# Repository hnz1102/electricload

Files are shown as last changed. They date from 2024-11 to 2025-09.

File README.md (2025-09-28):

<div align="center">
  <h1><code>Electric Load and Logger</code></h1>
  <p>
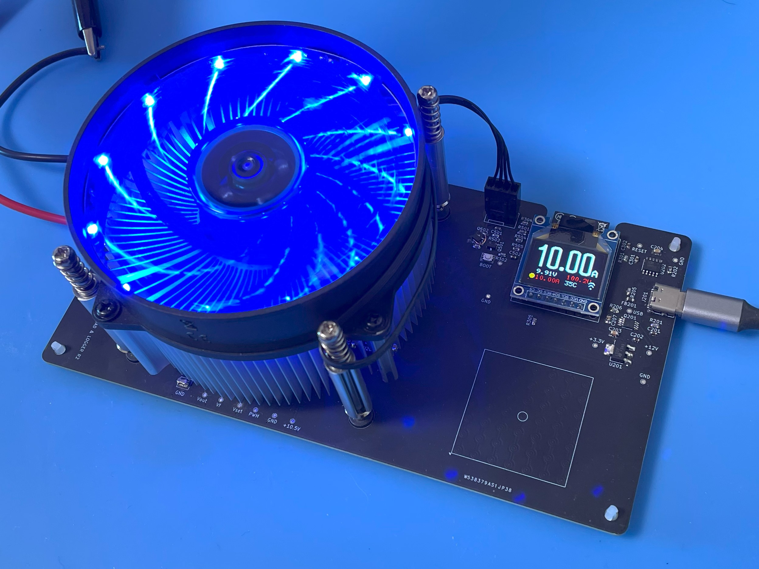
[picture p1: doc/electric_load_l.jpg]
    
  </p>
</div>

# Electric Load and Logger

This is an Electric Load and Logger. It can consume the power of the device and send the data to the server.
The maximum power is 100W, maximum voltage is 30V, and maximum current is 10A. But, it must be used under 100W.
And it can measure the voltage, current, and power consumption of the device and send the data to the InfluxDB server. You can see the data on the Dashboard.

# Feature

**High Power** - It can measure the power consumption of the device up to 100W.

**Controllable** - You can control the current consumption by the device. The current can be controlled every 10mA from 10mA to 10A.

**Auto Control** - The current consumption can be controlled automatically by the device using the PID controller.

**High-resolution** - By using Texas Instruments INA228 IC - 20-bit delta-sigma ADC, It can be got measurement data with 195.uV Bus voltage and 163.84mV Shunt voltage. 

**Microcontroller on board** - No need for a client PC when you are measuring. Directly send to the server. 

**Transfer measurement data via WiFi** - This Logger can transfer data to Linux PC via WiFi network and you can see the dashboard graph in influxDB.

**Internal Memory Buffer** - If the WiFi connection is not established, the data is stored in the internal memory buffer. When the WiFi connection is established, the data is sent to the server.

# How to use the Electric Load and Logger

At first, connect the power supply to this electric load as shown in the image below. The Plus line is connected to the 'Input +' terminal, and the GND line is connected to the 'Input -' terminal. And Input- is connected to the GND terminal, and Input+ is connected to the 'VBUS' terminal. This allows the device to measure the voltage.
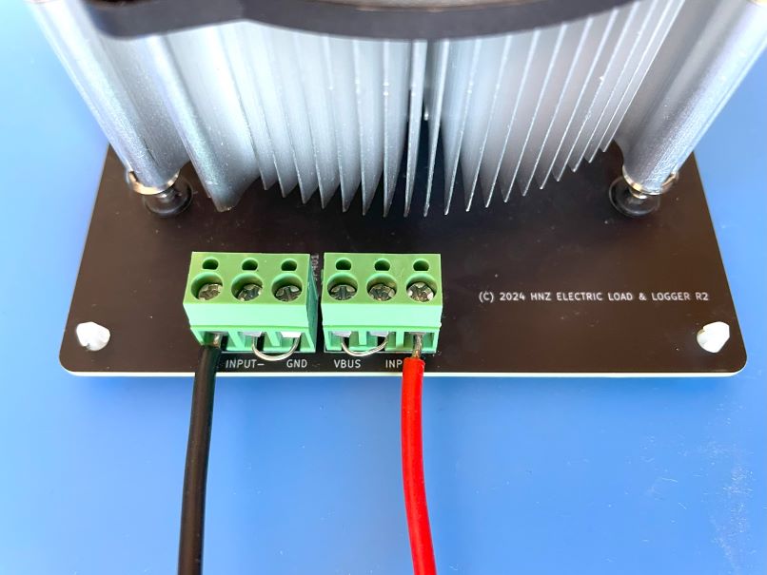
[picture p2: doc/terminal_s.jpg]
terminal


Then, connect the USB Power Delivery (PD) line to the USB-C port. The PD line must be connected to the USB PD Charger. This load gets power from the USB PD 12V.

After connecting the power supply, the display will show the current voltage, current, and power consumption. Then, you can set the current consumption by the device using the touch pad. Clockwise rotation increases the current, and counterclockwise rotation decreases the current. The current can be controlled every 10mA from 10mA to 10A. Fast rotation will increase or decrease the current quickly every 100mA. After setting the current, press the Center Position of the touch pad during over a second to start the load and measurement. The current consumption can be controlled automatically by the device using the PID controller.

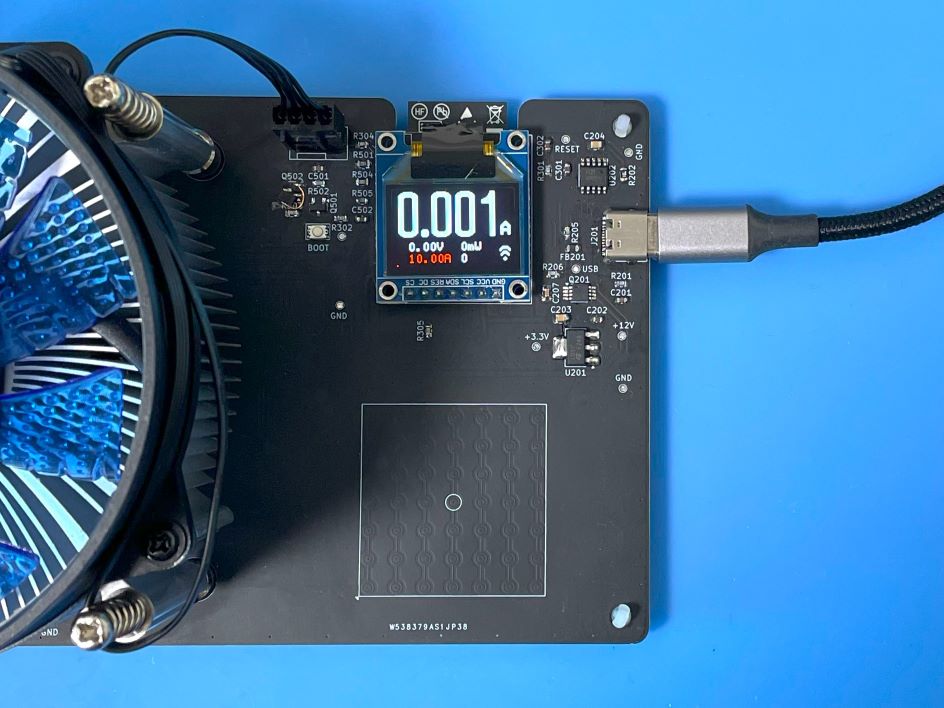
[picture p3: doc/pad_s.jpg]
pad


The display shows the current, voltage, power consumption, target current, temperature, PWM duty and status of the load. 
If you start the load, the display shows the yellow color circle in the left bottom corner and blinking. If the load is stopped, the circle disappears.
After the measure, the data is sent to the server. If the WiFi connection is not established, the data is stored in the internal memory buffer. When the WiFi connection is established, the data is sent to the server. However, the memory buffer is not stored more than 4096 samples. If the some data is stored in the memory buffer, the display shows the red bar in the bottom of the display. 

You can see the realtime data using Dashboard by [InfluxDB](https://www.influxdata.com/influxdb/).

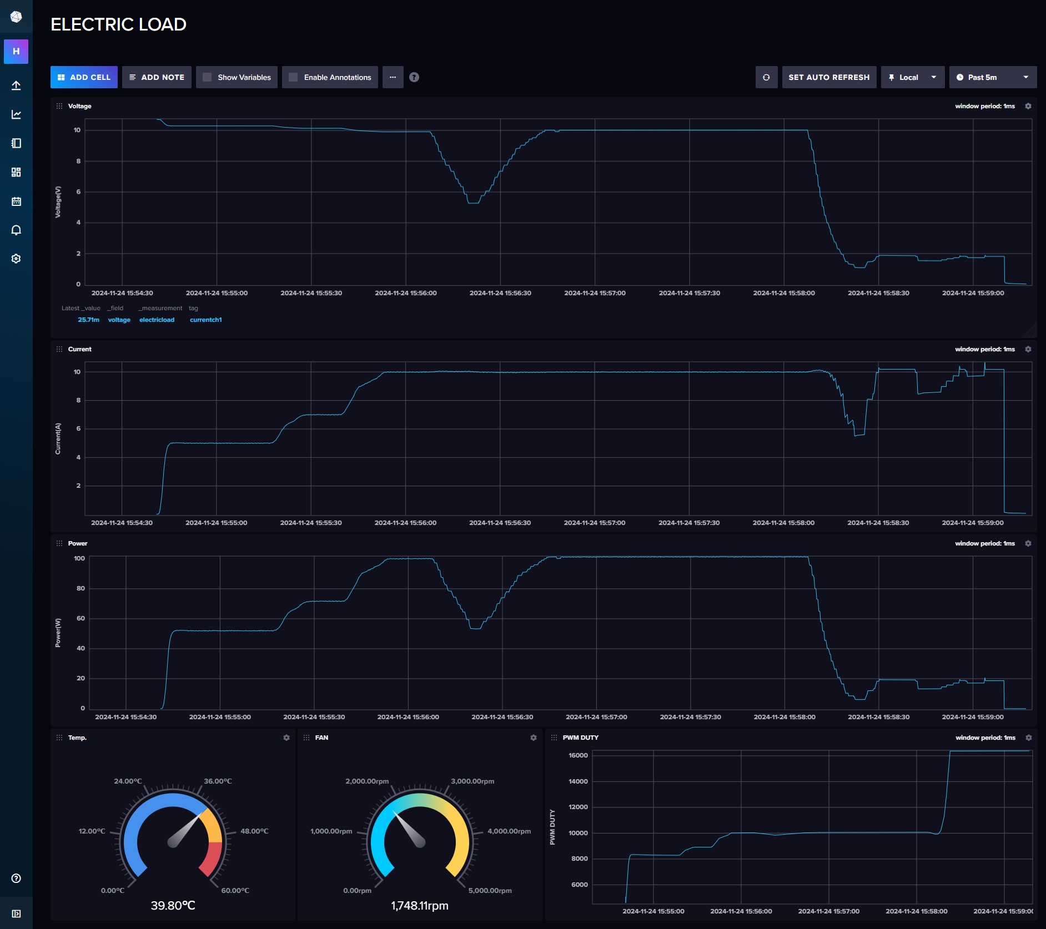
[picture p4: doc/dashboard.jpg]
dashboard


After the measure, to stop logging, press the Center Position of the touch pad during over a second. The load is stopped and the data is not sent to the server.

The dashboard shows the graphs of voltage, current, power consumption, and PWM duty. The temperature of the heat sink and FAN RPM also shown in the dashboard. 

# How to build from code and Install to the unit.

Using Ubuntu 22.04.3 LTS and ESP-IDF V5.2.1

## Prerequisites
Ensure that your system meets the following requirements before proceeding with the installation:
- Operating System: Linux-based distribution
- Required Packages: git, python3, python3-pip, gcc, build-essential, curl, pkg-config, libudev-dev, libtinfo5, clang, libclang-dev, llvm-dev, udev, libssl-dev, python3.10-venv

## Installation Steps

### 1. System Update and Package Installation
Update your system and install the necessary packages using:
```bash
sudo apt update && sudo apt -y install git python3 python3-pip gcc build-essential curl pkg-config libudev-dev libtinfo5 clang libclang-dev llvm-dev udev libssl-dev python3.10-venv
```

### 2. Rust Installation
Install Rust programming language and Cargo package manager:
```bash
curl --proto '=https' --tlsv1.2 -sSf https://sh.rustup.rs | sh
```
After installation, activate Rust by sourcing the environment:
```bash
. "$HOME/.cargo/env"
```

### 3. Additional Tools Installation
Install the following Rust tools:
- ldproxy
- espup
- cargo-espflash

Use the following commands:
```bash
cargo install ldproxy
cargo install espup
cargo install cargo-espflash
```
2024-08-12, cargo-espflash can not be compiled.
If you have an error, use the following command.
```bash
cargo install cargo-binstall
cargo binstall cargo-espflash 
```

### 4. ESP Environment Setup
Run the following command to install and update the Espressif Rust ecosystem:
```bash
espup install
espup update
```
Set up environment variables:
```bash
. ./export-esp.sh
```

### 5. Udev Rules Configuration
Configure udev rules for device permissions:
```bash
sudo sh -c 'echo "SUBSYSTEMS==\"usb\", ATTRS{idVendor}==\"303a\", ATTRS{idProduct}==\"1001\", MODE=\"0666\"" > /etc/udev/rules.d/99-esp32.rules'
sudo udevadm control --reload-rules
sudo udevadm trigger
```

### 6. Clone Repository
Clone the TimeLeapCam repository:
```bash
git clone https://github.com/hnz1102/electricload.git
cd electricload/code
```

### 7. Setting WiFi SSID, Password, etc.
Change the following configuration file: `cfg.toml`
You have to set the following parameters. WiFi SSID, Password, InfluxDB Server IP Address, InfluxDB API Key, and InfluxDB API with your ORG.
You can get the API Key from the InfluxDB Web Console. Please see the 'How to Install the influxDB and Configure the Dashboard' section No.3.

```bash
[electricload]
wifi_ssid = "<Your AP SSID>"  # Set your AP SSID
wifi_psk = "<Your AP Password>" # Set your AP Password
http_server = "<InfluxDB Server IP Address:Port>" # Set your InfluxDB Server IP Address and Port ex. 192.168.1.100:8086
pid_kp = "0.001"
pid_ki = "0.022"
pid_kd = "0.00001"
pwm_offset = "4500"
max_current_limit = "15.0"
max_power_limit = "105.0"
influxdb_api_key = "<InfluxDB API KEY>" # Set your InfluxDB API Key
influxdb_api = "/api/v2/write?org=<ORG>&bucket=LOGGER&precision=ns" # Set your InfluxDB API with your ORG and BUCKET ex. /api/v2/write?org=ORG&bucket=LOGGER&precision=ns
influxdb_tag = "currentch1"
influxdb_measurement = "electricload"
```

### 8. Build and Flash
Build the project.
```bash
cargo build --release
```

### 9. Flash the Firmware
Connect the Electric Load and Logger to your PC using a USB cable. Then, flash the firmware:
```bash
cargo espflash flash --release --monitor
```

If your device is not detected, power on the device and during the boot, press the `BOOT` button.
Then, run the flash command again.

### 10. Monitor the Output
After flashing the firmware, the console shows the booting messages.
```bash
[2024-11-24T08:43:44Z INFO ] 🚀 A new version of cargo-espflash is available: v3.2.0
[2024-11-24T08:43:44Z INFO ] Serial port: '/dev/ttyACM0'
[2024-11-24T08:43:44Z INFO ] Connecting...
[2024-11-24T08:43:44Z INFO ] Using flash stub
Finished `release` profile [optimized] target(s) in 0.19s
Chip type:         esp32s3 (revision v0.1)
Crystal frequency: 40 MHz
Flash size:        16MB
Features:          WiFi, BLE
MAC address:       xx:xx:xx:xx:xx:xx
Bootloader:        /esp32/electricload/code/target/xtensa-esp32s3-espidf/release/build/esp-idf-sys-37f4c3bc37bda4bb/out/build/bootloader/bootloader.bin
Partition table:   partitions.csv
App/part. size:    1,358,304/15,728,640 bytes, 8.64%
[2024-11-24T08:43:45Z INFO ] Segment at address '0x0' has not changed, skipping write
[2024-11-24T08:43:45Z INFO ] Segment at address '0x8000' has not changed, skipping write
[2024-11-24T08:43:46Z INFO ] Segment at address '0x10000' has not changed, skipping write
[2024-11-24T08:43:46Z INFO ] Flashing has completed!
Commands:
    CTRL+R    Reset chip
    CTRL+C    Exit

ESP-ROM:esp32s3-20210327
Build:Mar 27 2021
rst:0x15 (USB_UART_CHIP_RESET),boot:0x8 (SPI_FAST_FLASH_BOOT)
Saved PC:0x40378bb6
0x40378bb6 - rtc_isr
    at ??:??
SPIWP:0xee
mode:DIO, clock div:2
load:0x3fce3810,len:0x178c
load:0x403c9700,len:0x4
load:0x403c9704,len:0xcbc
load:0x403cc700,len:0x2d9c
entry 0x403c9914
I (27) boot: ESP-IDF v5.2.2 2nd stage bootloader
I (27) boot: compile time Nov 22 2024 19:30:56
I (27) boot: Multicore bootloader
I (30) boot: chip revision: v0.1
I (34) boot.esp32s3: Boot SPI Speed : 40MHz
I (39) boot.esp32s3: SPI Mode       : DIO
I (44) boot.esp32s3: SPI Flash Size : 16MB
I (49) boot: Enabling RNG early entropy source...
I (54) boot: Partition Table:
I (58) boot: ## Label            Usage          Type ST Offset   Length
I (65) boot:  0 nvs              WiFi data        01 02 00009000 00006000
I (72) boot:  1 phy_init         RF data          01 01 0000f000 00001000
I (80) boot:  2 factory          factory app      00 00 00010000 00f00000
I (87) boot: End of partition table
I (91) esp_image: segment 0: paddr=00010020 vaddr=3c0e0020 size=52034h (335924) map
I (183) esp_image: segment 1: paddr=0006205c vaddr=3fc9ae00 size=04ce8h ( 19688) load
I (189) esp_image: segment 2: paddr=00066d4c vaddr=40374000 size=092cch ( 37580) load
I (200) esp_image: segment 3: paddr=00070020 vaddr=42000020 size=ddea0h (908960) map
I (427) esp_image: segment 4: paddr=0014dec8 vaddr=4037d2cc size=0dae8h ( 56040) load
I (453) boot: Loaded app from partition at offset 0x10000
I (453) boot: Disabling RNG early entropy source...
I (464) cpu_start: Multicore app
I (465) octal_psram: vendor id    : 0x0d (AP)
I (465) octal_psram: dev id       : 0x02 (generation 3)
I (468) octal_psram: density      : 0x03 (64 Mbit)
I (473) octal_psram: good-die     : 0x01 (Pass)
I (478) octal_psram: Latency      : 0x01 (Fixed)
I (484) octal_psram: VCC          : 0x01 (3V)
I (489) octal_psram: SRF          : 0x01 (Fast Refresh)
I (495) octal_psram: BurstType    : 0x01 (Hybrid Wrap)
I (500) octal_psram: BurstLen     : 0x01 (32 Byte)
I (506) octal_psram: Readlatency  : 0x02 (10 cycles@Fixed)
I (512) octal_psram: DriveStrength: 0x00 (1/1)
I (518) MSPI Timing: PSRAM timing tuning index: 4
I (523) esp_psram: Found 8MB PSRAM device
I (527) esp_psram: Speed: 80MHz
I (543) cpu_start: Pro cpu start user code
I (543) cpu_start: cpu freq: 160000000 Hz
I (543) cpu_start: Application information:
I (546) cpu_start: Project name:     libespidf
I (551) cpu_start: App version:      9e8d2c8-dirty
I (557) cpu_start: Compile time:     Nov 22 2024 19:30:46
I (563) cpu_start: ELF file SHA256:  000000000...
I (568) cpu_start: ESP-IDF:          v5.2.2
I (573) cpu_start: Min chip rev:     v0.0
I (578) cpu_start: Max chip rev:     v0.99 
I (582) cpu_start: Chip rev:         v0.1
I (587) heap_init: Initializing. RAM available for dynamic allocation:
I (594) heap_init: At 3FCA4390 len 00045380 (276 KiB): RAM
I (600) heap_init: At 3FCE9710 len 00005724 (21 KiB): RAM
I (607) heap_init: At 3FCF0000 len 00008000 (32 KiB): DRAM
I (613) heap_init: At 600FE010 len 00001FD8 (7 KiB): RTCRAM
I (619) esp_psram: Adding pool of 8192K of PSRAM memory to heap allocator
I (627) spi_flash: detected chip: gd
I (631) spi_flash: flash io: dio
W (635) pcnt(legacy): legacy driver is deprecated, please migrate to `driver/pulse_cnt.h`
W (643) i2c: This driver is an old driver, please migrate your application code to adapt `driver/i2c_master.h`
W (654) timer_group: legacy driver is deprecated, please migrate to `driver/gptimer.h`
W (663) ADC: legacy driver is deprecated, please migrate to `esp_adc/adc_oneshot.h`
I (671) sleep: Configure to isolate all GPIO pins in sleep state
I (678) sleep: Enable automatic switching of GPIO sleep configuration
I (685) main_task: Started on CPU0
I (695) esp_psram: Reserving pool of 32K of internal memory for DMA/internal allocations
I (695) main_task: Calling app_main()
I (715) electricload: [Limit] Current: 15A  Power: 105W
I (715) gpio: GPIO[15]| InputEn: 0| OutputEn: 0| OpenDrain: 0| Pullup: 0| Pulldown: 0| Intr:0 
I (725) gpio: GPIO[16]| InputEn: 0| OutputEn: 0| OpenDrain: 0| Pullup: 0| Pulldown: 0| Intr:0 
I (735) electricload::displayctl: Start Display Thread.
I (735) electricload: INA228 Config: FB6A
I (735) electricload: current_lsb=3.125e-5 shunt_cal_val=2048.0 shunt_cal=2048
I (745) electricload: Max duty: 16383
I (755) electricload: Max duty: 255
I (755) gpio: GPIO[42]| InputEn: 0| OutputEn: 0| OpenDrain: 0| Pullup: 0| Pulldown: 0| Intr:0 
I (765) gpio: GPIO[41]| InputEn: 0| OutputEn: 0| OpenDrain: 0| Pullup: 0| Pulldown: 0| Intr:0 
I (775) electricload::pulscount: Start puls count thread.
I (785) pp: pp rom version: e7ae62f
I (785) net80211: net80211 rom version: e7ae62f
I (805) wifi:wifi driver task: 3fcc2b98, prio:23, stack:6656, core=0
I (805) wifi:wifi firmware version: 3e0076f
I (805) wifi:wifi certification version: v7.0
I (805) wifi:config NVS flash: disabled
I (805) wifi:config nano formating: disabled
I (815) wifi:Init data frame dynamic rx buffer num: 32
I (815) wifi:Init static rx mgmt buffer num: 10
I (825) wifi:Init management short buffer num: 32
I (825) wifi:Init static tx buffer num: 16
I (825) wifi:Init tx cache buffer num: 32
I (835) wifi:Init static tx FG buffer num: 2
I (835) wifi:Init static rx buffer size: 1600
I (845) wifi:Init static rx buffer num: 10
I (845) wifi:Init dynamic rx buffer num: 32
I (845) wifi_init: rx ba win: 6
I (965) wifi_init: tcpip mbox: 32
I (965) wifi_init: udp mbox: 6
I (965) wifi_init: tcp mbox: 6
I (965) wifi_init: tcp tx win: 5760
I (975) wifi_init: tcp rx win: 5760
I (975) wifi_init: tcp mss: 1440
I (985) wifi_init: WiFi IRAM OP enabled
I (985) wifi_init: WiFi RX IRAM OP enabled
I (995) phy_init: phy_version 670,b7bc9b9,Apr 30 2024,10:54:13
I (1035) wifi:mode : sta ()
I (1035) wifi:enable tsf
I (3985) wifi:new:<4,0>, old:<1,0>, ap:<255,255>, sta:<4,0>, prof:1
I (3985) wifi:state: init -> auth (b0)
I (3985) wifi:state: auth -> assoc (0)
I (3995) wifi:state: assoc -> run (10)
I (4005) wifi:connected with xxxxxxxx, aid = 7, channel 4, BW20, bssid = xx:xx:xx:xx:xx:xx
I (4005) wifi:security: WPA2-PSK, phy: bgn, rssi: -36
I (4005) wifi:pm start, type: 1
I (4005) wifi:dp: 1, bi: 102400, li: 3, scale listen interval from 307200 us to 307200 us
I (4015) wifi:set rx beacon pti, rx_bcn_pti: 0, bcn_timeout: 25000, mt_pti: 0, mt_time: 10000
I (4025) wifi:AP's beacon interval = 102400 us, DTIM period = 1
I (4065) electricload::wifi: Wifi connected
I (4065) esp_idf_svc::sntp: Initializing
I (4065) esp_idf_svc::sntp: Initialization complete
I (4065) electricload: NTP Sync Start..
I (7475) electricload: NTP Sync Completed: 2024-11-24 08:43:53
I (7475) electricload::transfer: Start transfer thread.
I (7475) electricload::touchpad: Start TouchPad Read Thread.
I (7485) gpio: GPIO[18]| InputEn: 0| OutputEn: 0| OpenDrain: 0| Pullup: 0| Pulldown: 0| Intr:0 
I (7495) electricload: PID Controller: KP=0.001 KI=0.022 KD=0.00001
I (7585) electricload::touchpad: TouchPad4 threshold: 1529
I (7585) electricload::touchpad: TouchPad5 threshold: 1519
I (7585) electricload::touchpad: TouchPad6 threshold: 1433
I (7585) electricload::touchpad: TouchPad7 threshold: 1523
I (7595) electricload::touchpad: TouchPad8 threshold: 297
I (7605) electricload::touchpad: TouchPad3 threshold: 1436
I (7605) electricload::touchpad: TouchPad9 threshold: 291
I (7625) electricload::touchpad: TouchPad1 threshold: 325
I (7625) electricload::touchpad: TouchPad2 threshold: 1619
I (7625) electricload::touchpad: TouchPad14 threshold: 313
I (7645) electricload::touchpad: TouchPad13 threshold: 307
I (7645) electricload::touchpad: TouchPad12 threshold: 302
I (7645) electricload::touchpad: TouchPad11 threshold: 287
I (7645) electricload::touchpad: TouchPad10 threshold: 281
I (7665) electricload::touchpad: TouchPad charge discharge times: 500 -> 1000
```

## How to Install the influxDB and Configure the Dashboard

### 1. Download [influxDB](https://docs.influxdata.com/influxdb/v2.7/install/?t=Linux) and Install.
```bash
$ wget https://dl.influxdata.com/influxdb/releases/influxdb2-2.7.0-amd64.deb
$ sudo dpkg -i influxdb2-2.7.0-amd64.deb
$ sudo service influxdb start
```

### 2. Configure the influxDB

```
Connect to the 'http://<influxDB installed PC Address>:8086'
```
Click `GET STARTED` and set `Username`, `Password`, `Initial Organization Name`, and `Initial Bucket Name`
|Term|Value|
|---|---|
|Username|Set login username as influxDB administrator web console|
|Password|Set login password as influxDB administrator web console|
|Initial Organization Name| Organization Name ex. ORG|
|Initial Bucket Name| LOGGER |

After set them, click `CONTINUE`.

### 3. Copy the operator API token.

You can see the operator API token on the browser. YOU WON'T BE ABLE TO SEE IT AGAIN!
If you want to get new API token, click `API Tokens` menu form `Sources` Icon, then click `GENERATE API TOKEN` and select `All access token`, click `Save`.
You can see a new API token and get it.
After copy the token, click `CONFIGURE LATER`.

### 4. Import the Dashboard Template.

Click the `Dashboard` icon, and select `Import Dashboard` from the `CREATE DASHBOARD` menu.

Drop the `influxdb/electric_load.json` file to `Drop a file here`, then click `IMPORT JSON AS DASHBOARD`.

You can see the `ELECTRIC LOAD` pannel on the Dashboards page.

Click this panel, and You can see the dashboard.

If you want to customize the dashboard design, click configure mark. You can change the graph design.

## Schematic, PCB Gabar Data

There is a Schematic data in hardware directory. 
If you want to make the PCB, you can order the [PCBway](https://www.pcbway.com/project/shareproject/Digitally_Controlled_Electric_Load_504eb052.html) this link.
The heat sink is not included in the schematic data. You can use the heat sink with the fan for LGA115x CPU Cooler. 

I used this [heat sink](https://www.ainex.jp/products/cc-06b/)

I guess another [heat sink](https://www.tronwire.com/collections/tronwire-cpu-coolers/products/tw-10) is also good.

This PCB is designed by [Kicad](https://www.kicad.org/). This board image photo is shown the jumper wire. But, the PCB data is already fixed the error.

UPDATE 2024-12-29: I changed the OpAmp from TSB6111ILT to OPA187IDBVR. OPA187IDBVR is a low noise and low offset voltage OpAmp. It can be used for the high precision control.

# Changelog

## v0.1.2
- **PID Control Enhancement**: Improved PID controller performance for better current regulation and stability.
- **Under Voltage Protection**: Added `under_voltage_limit` configuration parameter. When the voltage drops below this threshold, the PID controller is reset to prevent inrush current during startup or low voltage conditions.
- **Overcurrent Protection**: Implemented overcurrent protection using `max_current_limit_ratio` parameter. When the actual current exceeds the set current multiplied by this ratio, the PID controller is reset and output is set to zero to protect against excessive current flow.
- **Inrush Current Suppression**: These protection mechanisms work together to suppress inrush current during startup and abnormal conditions, ensuring safer operation.

**Note: After updating to v0.1.2, it is necessary to reconfigure the `cfg.toml` file to include the new parameters. Some PID parameters are changed, so please update them accordingly.**

## v0.1.1
- **NVS Configuration Persistence**: Added functionality to save the last load current setting to NVS (Non-Volatile Storage) and restore it on the next startup. This allows the device to remember the previous current setting even after power cycles or resets.
- **ESP-IDF Update**: Updated ESP-IDF from v5.2.1 to v5.4.2 for improved stability and latest features.
- **WiFi Reconnection Enhancement**: Added automatic WiFi reconnection functionality to maintain network connectivity during temporary disconnections.
- **Voltage Measurement Correction**: Fixed bus voltage resolution from 193.3125µV to 195.3125µV for more accurate voltage measurements.

## LICENSE
This source code is licensed under MIT. Other Hardware Schematic documents are licensed under CC-BY-SA V4.0.

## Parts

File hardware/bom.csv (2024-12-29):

Reference | Value | Footprint | Qty | digikey | distributor
C201,C202,C205,C301,C302,C404,C405,C408,C410,C501,C502 | 0.1uF | Capacitor_SMD:C_0603_1608Metric | 11 | 311-1343-1-ND | https://www.digikey.com/en/products/detail/yageo/CC0603ZRY5V9BB104/2103081
C203,C206,C208,C401,C403 | 10uF | Capacitor_SMD:C_0805_2012Metric | 5 | 311-3494-1-ND | https://www.digikey.com/en/products/detail/murata-electronics/GRM21BR61C106KE15K/2546903
C204,C402,C406 | 1uF | Capacitor_SMD:C_0805_2012Metric | 3 | 311-1365-1-ND | https://www.digikey.jp/en/products/detail/yageo/CC0805KKX7R7BB105/2103103
C207 | 2.2uF | Capacitor_SMD:C_0805_2012Metric | 1 | 311-1463-1-ND | https://www.digikey.jp/en/products/detail/yageo/CC0805ZRY5V7BB225/2833628
C407 | 4.7uF | Capacitor_SMD:C_0805_2012Metric | 1 | 311-1907-1-ND | https://www.digikey.jp/en/products/detail/yageo/CC0805ZKY5V7BB475/5195313
C409 | 1000pF | Capacitor_SMD:C_0603_1608Metric | 1 | 311-4063-1-ND | https://www.digikey.jp/en/products/detail/yageo/CC0603KRX7R7BB102/5883752
D401 | MBR3060FCT | Package_TO_SOT_THT:TO-220-3_Horizontal_TabUp | 1 | 3757-MBR3060FCT_T0_00001-ND | https://www.digikey.jp/en/products/detail/panjit-international-inc/MBR3060FCT-T0-00001/15800233
FB201 | MH2029-601Y | Inductor_SMD:L_0805_2012Metric | 1 | MH2029-601YCT-ND | https://www.digikey.com/en/products/detail/bourns-inc/MH2029-601Y/3741762
J201 | USB4105-GF-A | Library:USB_C_5077CR-16-SMC2-BK-TR | 1 | 2073-USB4105-GF-ACT-ND | https://www.digikey.com/en/products/detail/gct/USB4105-GF-A/11198441
J301 | FingerTouchPad | Library:FingerTouchPad_34x35mm | 1
J401,J402 | Screw_Terminal_3P | Library:TB112-2-2-3-E-1 Terminal Block | 2 |  | https://akizukidenshi.com/catalog/g/g101310/
J501 | 4PIN FANCTL | Connector:FanPinHeader_1x04_P2.54mm_Vertical | 1 | WM4330-ND | https://www.digikey.jp/en/products/detail/molex/0470531000/2421261
Q201 | IRF7606TRPBF | Package_SO:MSOP-8_3x3mm_P0.65mm | 1 | IRF7606TRPBFCT-ND | https://www.digikey.jp/en/products/detail/infineon-technologies/IRF7606TRPBF/856652
Q401 | IRF530PBF | Package_TO_SOT_THT:TO-220-3_Horizontal_TabUp | 1 | IRF530PBF-ND | https://www.digikey.jp/en/products/detail/vishay-siliconix/IRF530PBF/811781
Q501 | 2N7002K | Package_TO_SOT_SMD:SOT-23 | 1 | 2N7002KCT-ND | https://www.digikey.jp/en/products/detail/onsemi/2N7002K/2060348
Q502 | SSM3J332R | Package_TO_SOT_SMD:SOT-23 | 1 | 4518-SSM3J332RCT-ND | https://www.digikey.jp/en/products/detail/umw/SSM3J332R/24889390
R201,R205,R206,R301,R302,R305,R402,R403,R404,R502,R503,R505 | 10K | Resistor_SMD:R_0603_1608Metric | 12 | 13-RC0603JR-1010KLCT-ND | https://www.digikey.com/en/products/detail/yageo/RC0603JR-1010KL/13694233
R202,R405,R411,R412,R501 | 1K 1% | Resistor_SMD:R_0603_1608Metric | 5 | 311-1.00KHRCT-ND | https://www.digikey.jp/en/products/detail/yageo/RC0603FR-071KL/726843
R203 | 75K 1% | Resistor_SMD:R_0603_1608Metric | 1 | YAG3629CT-ND | https://www.digikey.jp/en/products/detail/yageo/AC0603FR-0775KL/5896284
R204,R401,R410 | 10K 1% | Resistor_SMD:R_0603_1608Metric | 3 | 311-10.0KHRCT-ND | https://www.digikey.jp/en/products/detail/yageo/RC0603FR-0710KL/726880
R303,R304 | 150R | Resistor_SMD:R_0603_1608Metric | 2 | 311-150GRCT-ND | https://www.digikey.jp/en/products/detail/yageo/RC0603JR-07150RL/726714
R406 | 2K 1% | Resistor_SMD:R_0603_1608Metric | 1 | 311-2.00KHRCT-ND | https://www.digikey.jp/en/products/detail/yageo/RC0603FR-072KL/727009
R407,R504 | 100 | Resistor_SMD:R_0603_1608Metric | 2 | 311-100GRCT-ND | https://www.digikey.jp/en/products/detail/yageo/RC0603JR-07100RL/726697
R408,R409 | 10m | Library:R_10mOHM | 2 |  | https://akizukidenshi.com/catalog/g/gP-01886/
SW301 | 3.5x2.6 Tact SW | Library:WS-TASV SMT Tact Switch | 1 | 732-435151014824CT-ND | https://www.digikey.com/en/products/detail/w%C3%BCrth-elektronik/435151014824/11627325
TP-PAD401 | TPGND | Library:TestPoint_Pad_3.2x1.6mm | 1 | 2019-RCWCTECT-ND | https://www.digikey.jp/en/products/detail/koa-speer-electronics-inc/RCWCTE/11476558
TP201 | +3.3V | TestPoint:TestPoint_Pad_D1.0mm | 1
TP202 | VBUS | TestPoint:TestPoint_Pad_D1.0mm | 1
TP203 | +12V | TestPoint:TestPoint_Pad_D1.0mm | 1
TP301 | RESET | TestPoint:TestPoint_Pad_D1.0mm | 1
TP302 | BOOT | TestPoint:TestPoint_Pad_D1.0mm | 1
TP401 | PWM | TestPoint:TestPoint_Pad_D1.0mm | 1
TP402 | SET-Vr | TestPoint:TestPoint_Pad_D1.0mm | 1
TP403 | Vfb | TestPoint:TestPoint_Pad_D1.0mm | 1
TP404 | OP-VCC | TestPoint:TestPoint_Pad_D1.0mm | 1
TP405,TP406,TP407,TP408,TP409 | GND | TestPoint:TestPoint_Pad_D1.0mm | 5
TP410 | Vgs | TestPoint:TestPoint_Pad_D1.0mm | 1
U201 | LD1117S33TR | Package_TO_SOT_SMD:SOT-223-3_TabPin2 | 1 | 497-1242-1-ND | https://www.digikey.com/en/products/detail/stmicroelectronics/LD1117S33TR/585766
U202 | CH224K | Library:ESSOP-10_3.9x4.9mm_P1.00mm | 1 |  | https://akizukidenshi.com/catalog/g/g118023/
U203 | SPX3819M5-L | Package_TO_SOT_SMD:SOT-23-5 | 1 | 1016-1871-1-ND | https://www.digikey.com/en/products/detail/maxlinear-inc/SPX3819M5-L-TR/2472388
U301 | ESP32-S3-WROOM-1-N16R8 | Library:ESP32-S3-WROOM-1_EXP | 1 | 1965-ESP32-S3-WROOM-1-N16R8CT-ND | https://www.digikey.com/en/products/detail/espressif-systems/ESP32-S3-WROOM-1-N16R8/16162642
U302 | SSD1331_DISPLAY | Library:OLED SSD1331 SPI DISPLAY | 1 |  | https://akizukidenshi.com/catalog/g/gP-14435/
U401 | OPA187IDBVR | Package_TO_SOT_SMD:SOT-23-5 | 1 | 296-53156-1-ND | https://www.digikey.com/en/products/detail/texas-instruments/OPA187IDBVR/9861469
U402 | INA228 | Package_SO:VSSOP-10_3x3mm_P0.5mm | 1 | 296-INA228AIDGSRCT-ND | https://www.digikey.com/en/products/detail/texas-instruments/INA228AIDGSR/13691042
U403 | LM35-NEB | Package_TO_SOT_THT:TO-220-3_Horizontal_TabDown | 1 | LM35DT/NOPB-ND | https://www.digikey.jp/en/products/detail/texas-instruments/LM35DT-NOPB/362706
U404 | TSB611ILT | Package_TO_SOT_SMD:SOT-23-5 | 1 | 497-16082-1-ND | https://www.digikey.jp/en/products/detail/stmicroelectronics/TSB611ILT/5639707

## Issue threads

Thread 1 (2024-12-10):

No issue at all, just congrats!

Karim-at-Powl, 2024-12-10:
That is such an elegant solution, ironically _exactly_ what I wanted to build!
You use INA228, you use ESP32-S3, you use Kicad.. heaven!
Found you through PCBway :)

I read something that might be interesting for you: Instead of using a single 14-bit PWM signal and LPF to control the FET-OPamp, you can instead have two or more PWM signals with different Filters wired in parallel. Imagine one main PWM with R = 1 kOhm and one auxiliary PWM with R = 10 kOhm. You can then use the auxPWM for fine tuning while maintaining high Frequency and good response time on the main PWM. Good luck!

hnz1102, 2024-12-11:
Thank you!

>  I read something that might be interesting for you: Instead of using a single 14-bit PWM signal and LPF to control the FET-OPamp, you can instead have two or more PWM signals with different Filters wired in parallel. Imagine one main PWM with R = 1 kOhm and one auxiliary PWM with R = 10 kOhm. You can then use the auxPWM for fine tuning while maintaining high Frequency and good response time on the main PWM.

That's good idea! I will try it with using unoccupied GPIO pin.

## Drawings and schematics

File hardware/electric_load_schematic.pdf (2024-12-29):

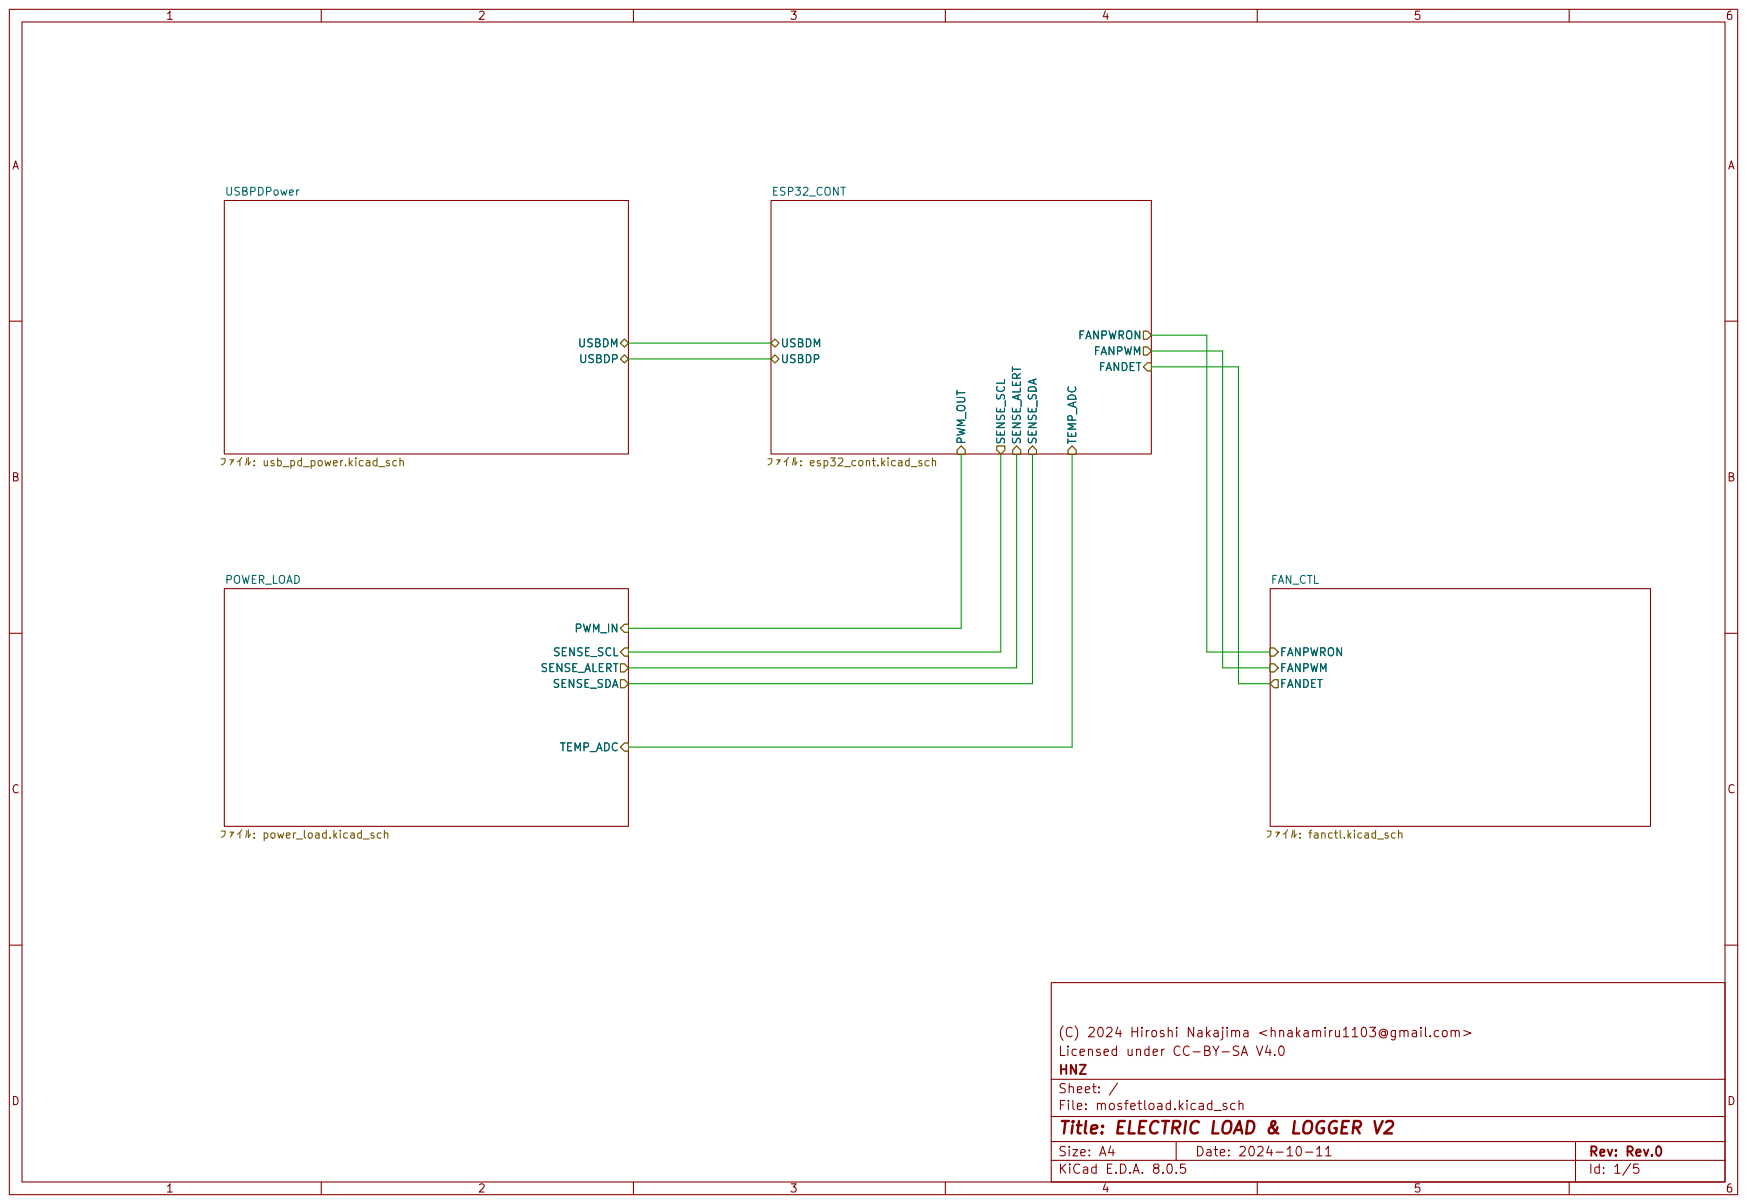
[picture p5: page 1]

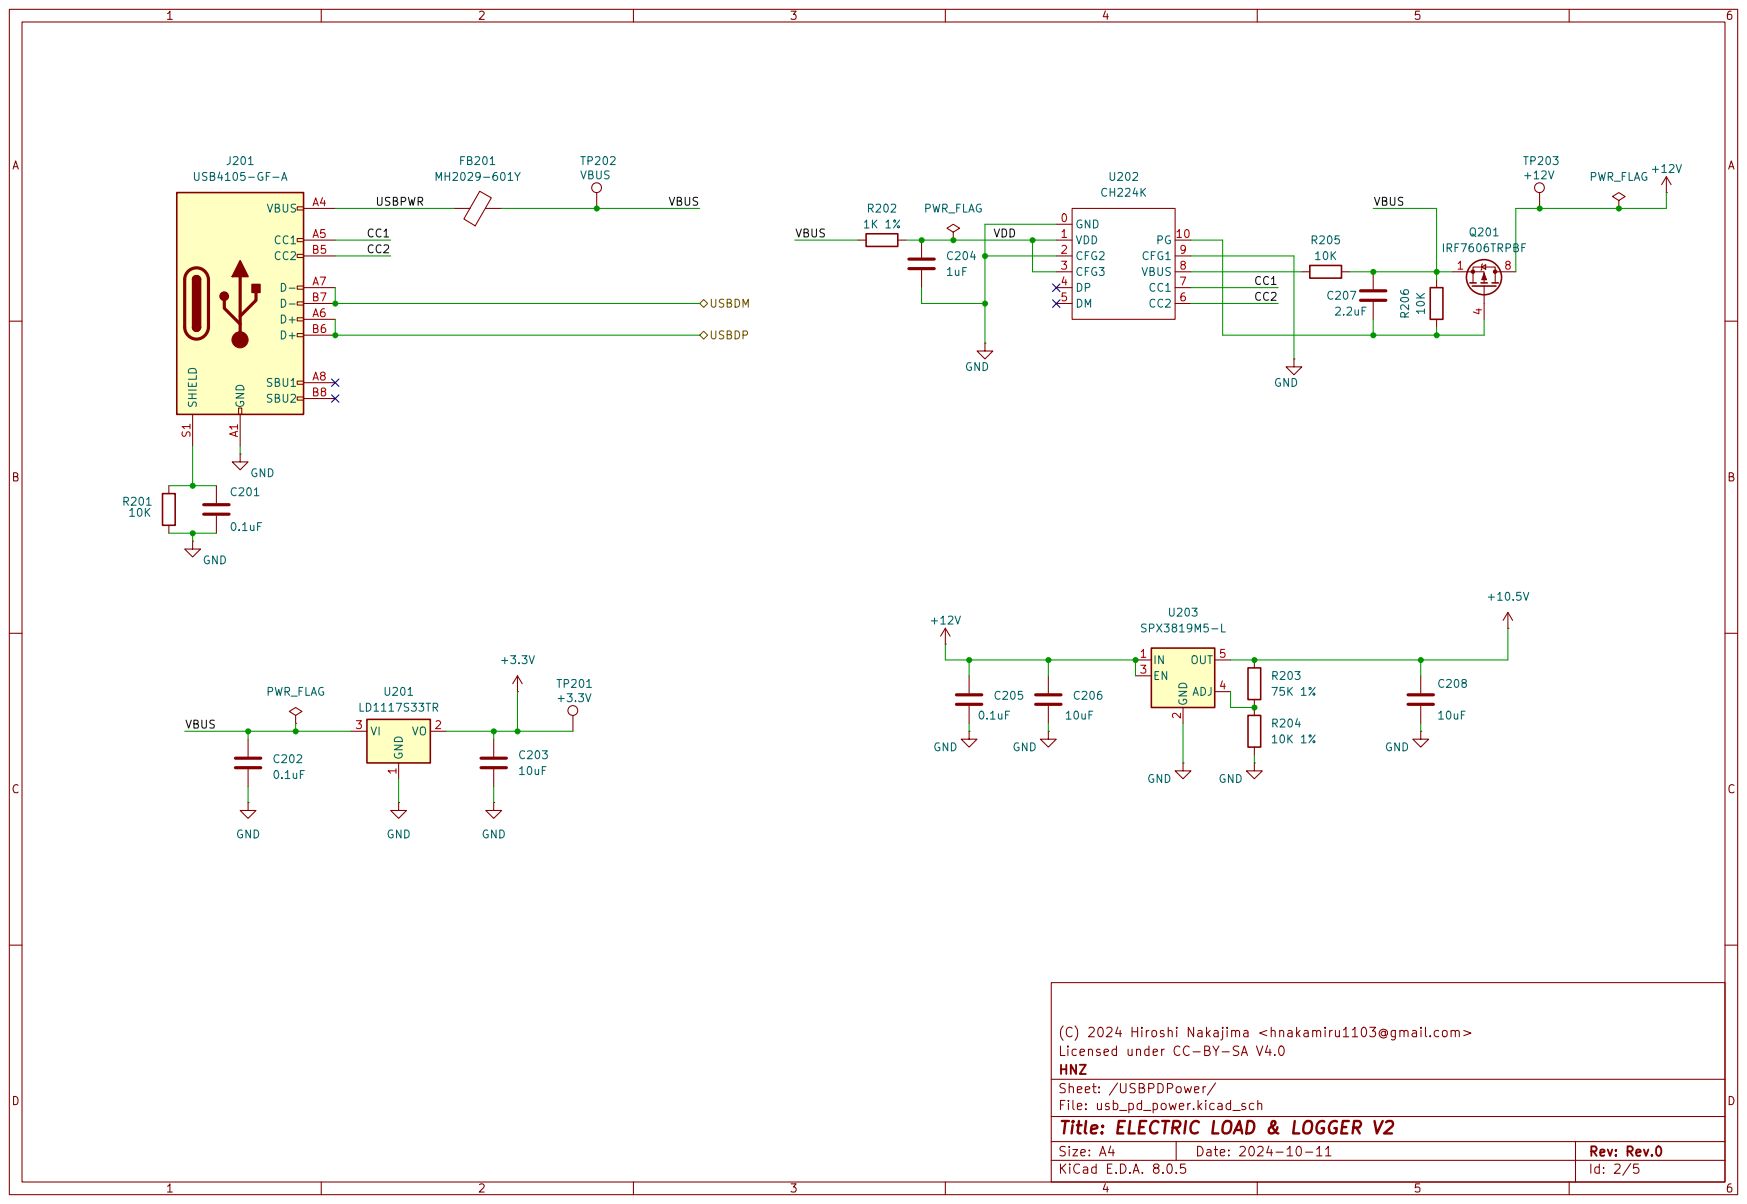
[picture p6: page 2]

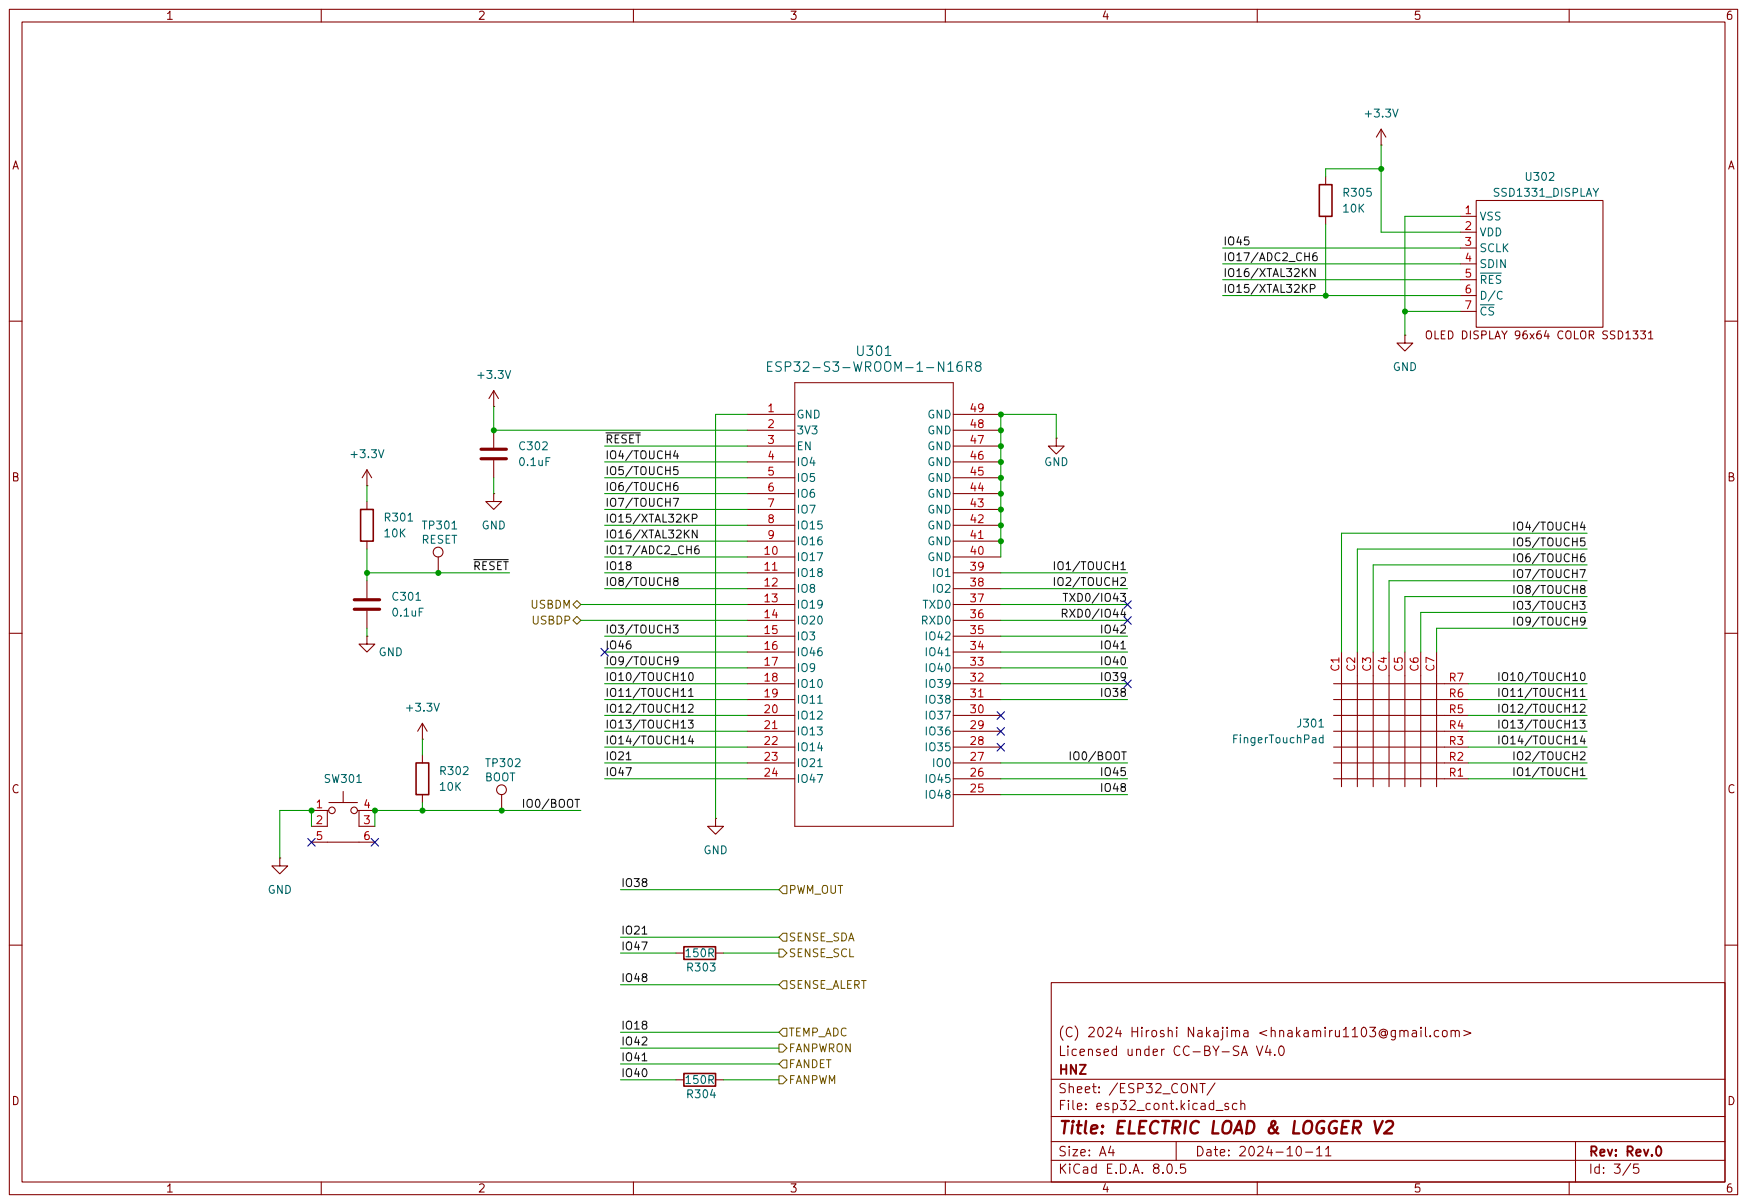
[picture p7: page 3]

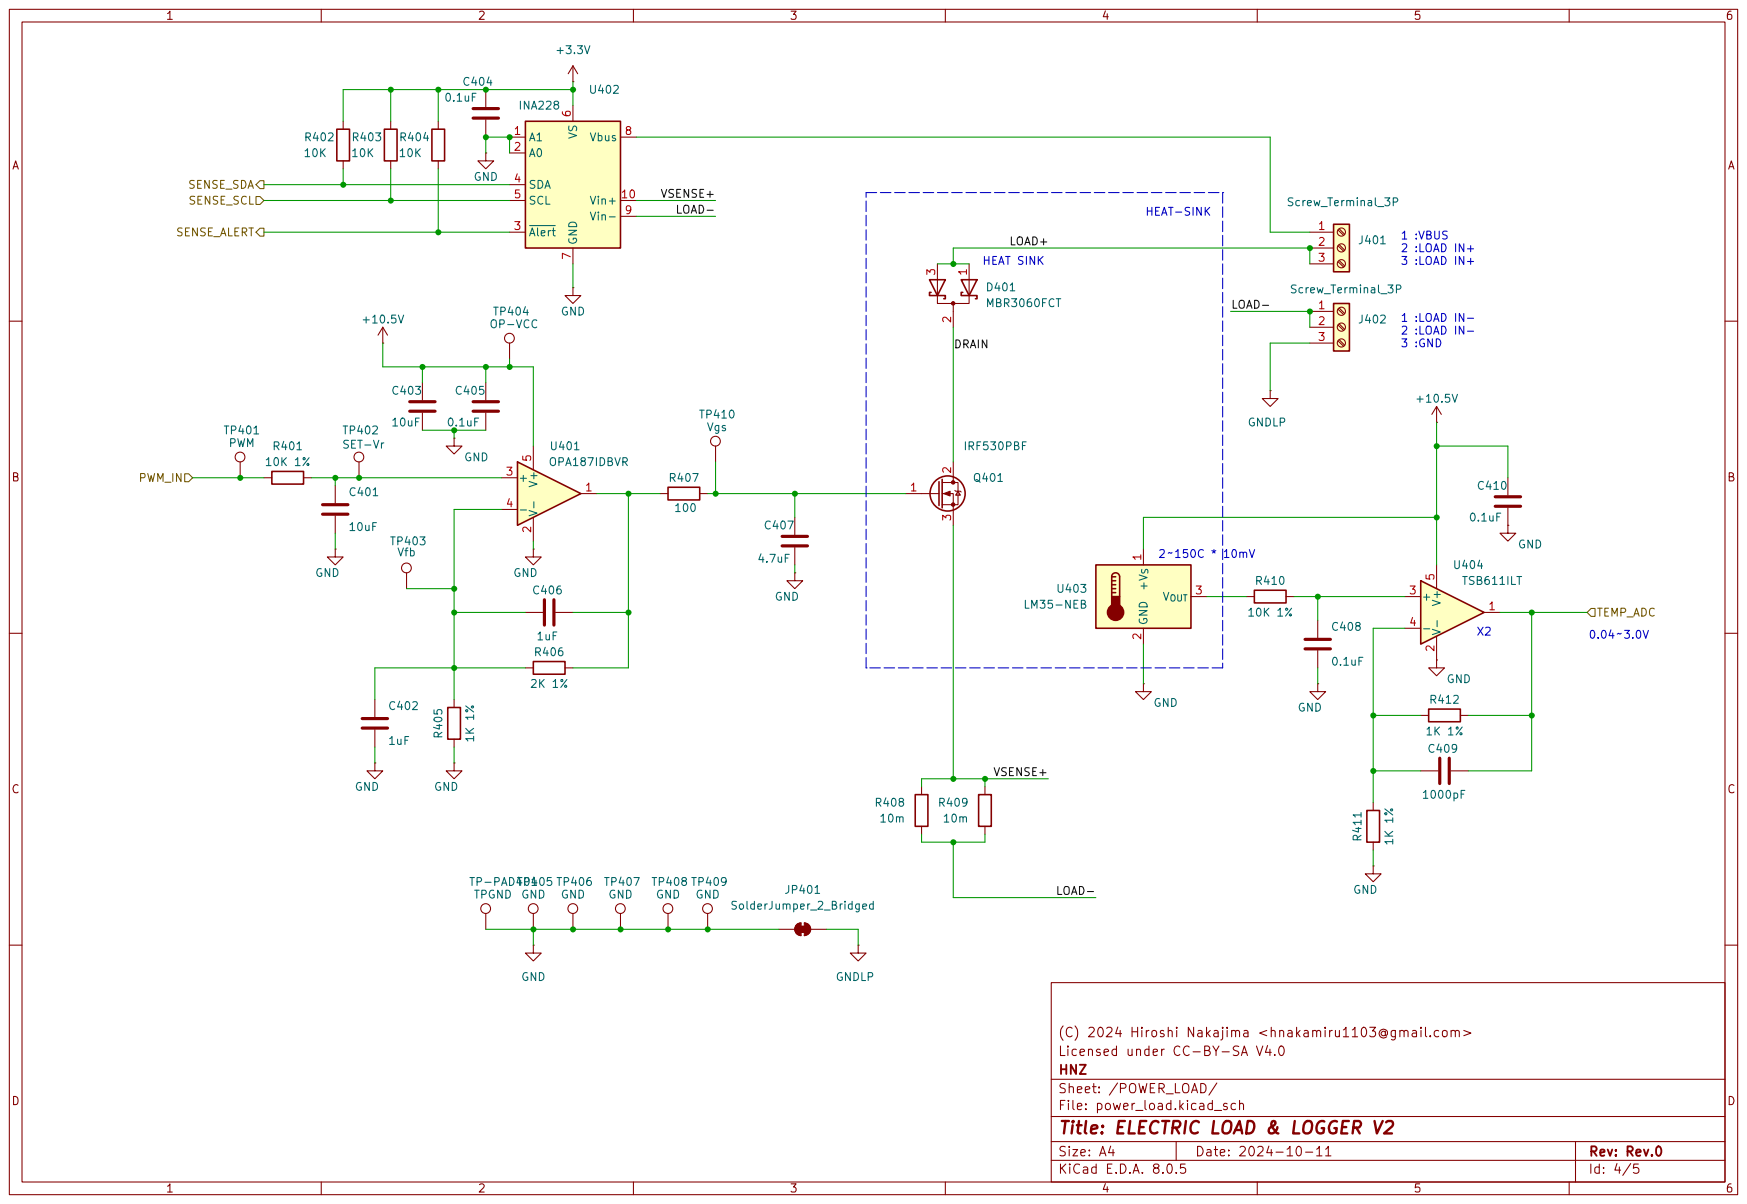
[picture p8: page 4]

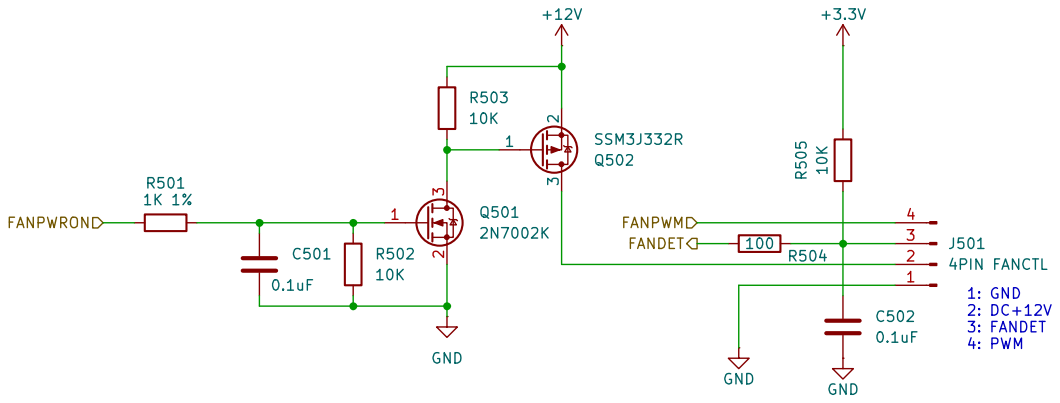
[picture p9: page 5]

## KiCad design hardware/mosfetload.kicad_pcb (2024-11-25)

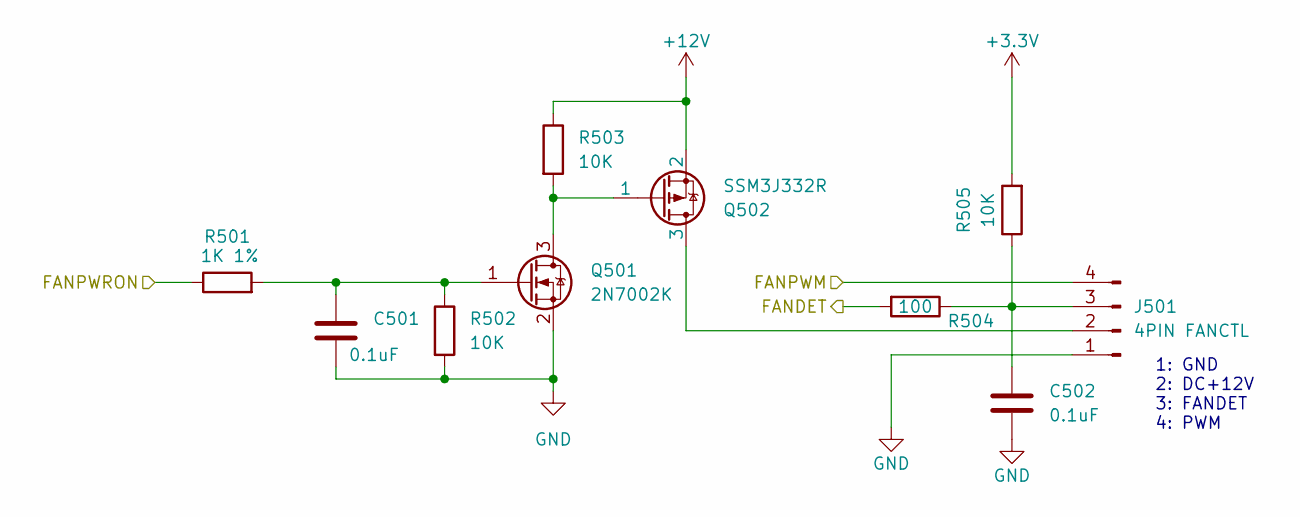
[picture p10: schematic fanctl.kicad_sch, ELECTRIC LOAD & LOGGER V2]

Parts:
C501, C502: 0.1uF; C_0603_1608Metric; digikey 311-1343-1-ND
J501: 4PIN FANCTL; FanPinHeader_1x04_P2.54mm_Vertical
Q501: 2N7002K; SOT-23; digikey 2N7002KCT-ND
Q502: SSM3J332R; SOT-23; digikey 4518-SSM3J332RCT-ND
R501: 1K 1%; R_0603_1608Metric; digikey 311-1.00KHRCT-ND
R502, R503, R505: 10K; R_0603_1608Metric; digikey 13-RC0603JR-1010KLCT-ND
R504: 100; R_0603_1608Metric; digikey 311-100GRCT-ND

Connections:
+3.3V: R505.2; also elsewhere on the board
+12V: Q502.2, R503.1; also elsewhere on the board
/ESP32_CONT/FANPWM: J501.4; also elsewhere on the board
/ESP32_CONT/IO41: R504.2; also elsewhere on the board
/ESP32_CONT/IO42: R501.1; also elsewhere on the board
GND: C501.2, C502.2, J501.1, Q501.2 (S), R502.2; also elsewhere on the board
unnamed: J501.2, Q502.3
unnamed: C502.1, J501.3, R504.1, R505.1
unnamed: Q501.3 (D), Q502.1, R503.2
unnamed: C501.1, Q501.1 (G), R501.2, R502.1

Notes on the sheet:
1: GND 2: DC+12V 3: FANDET 4: PWM

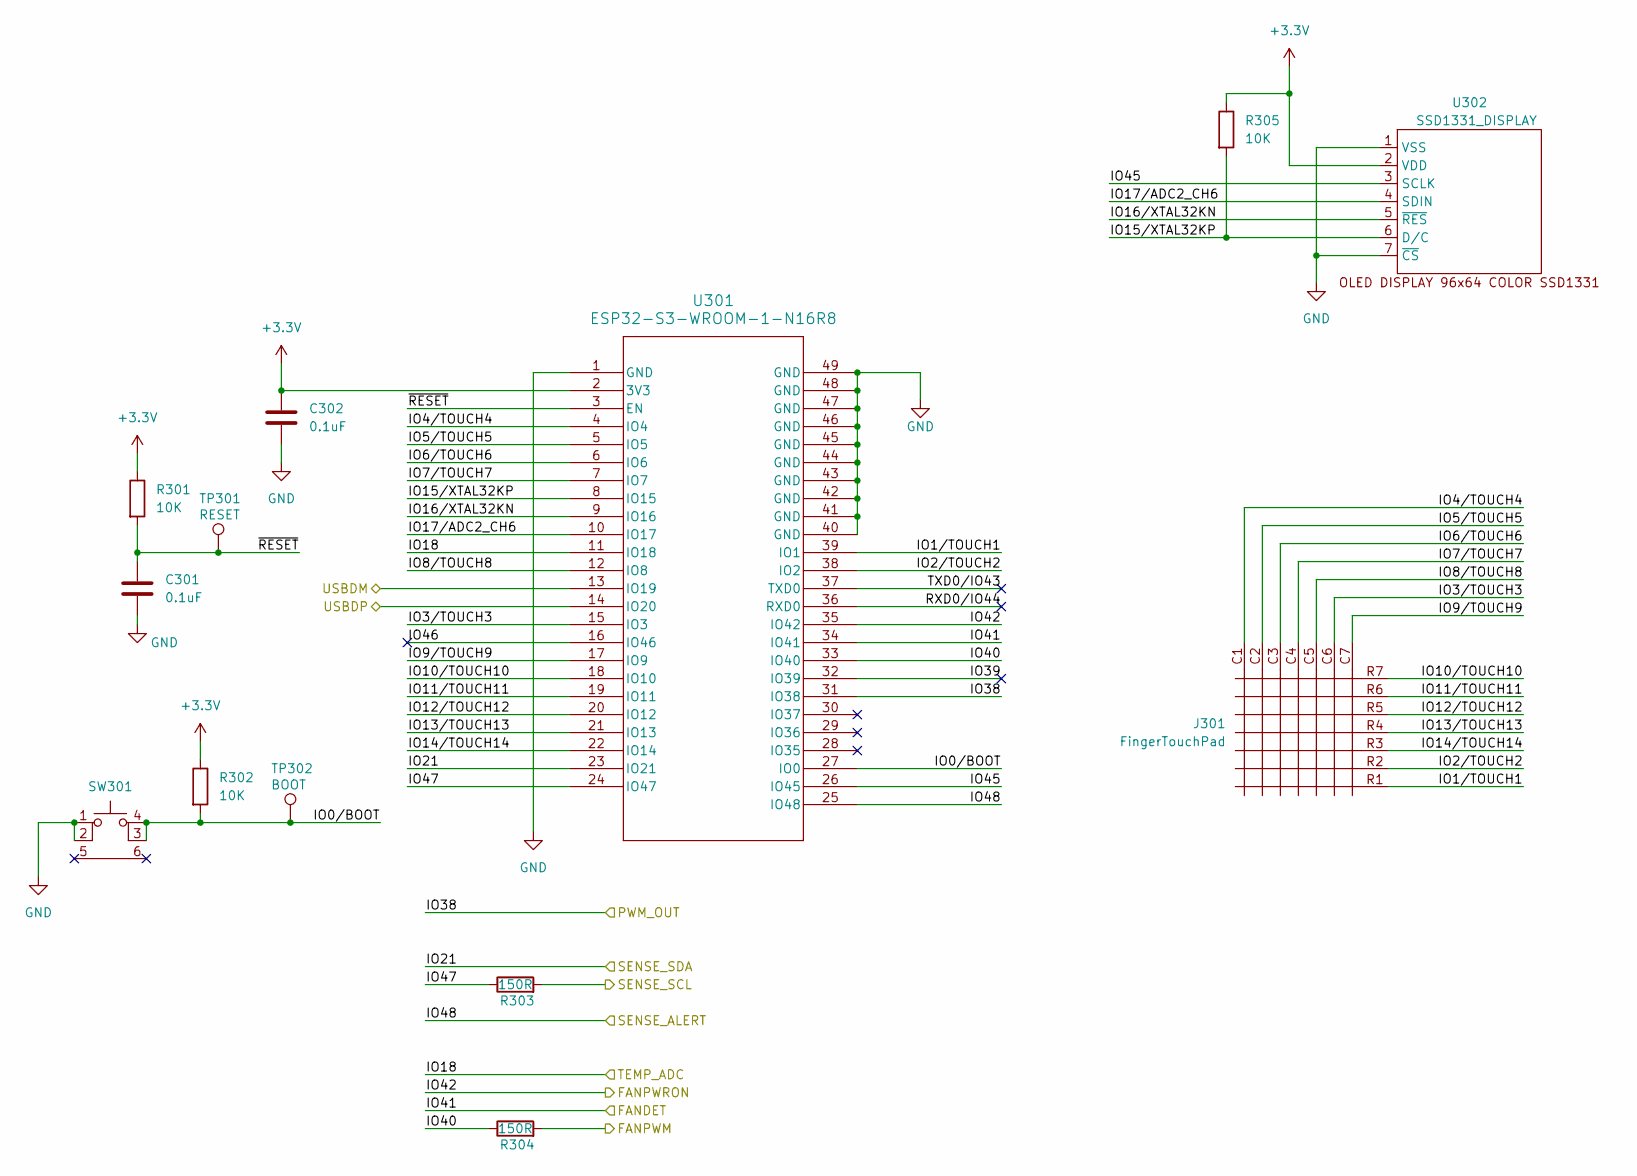
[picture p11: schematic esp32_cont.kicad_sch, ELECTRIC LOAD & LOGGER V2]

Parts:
C301, C302: 0.1uF; C_0603_1608Metric; digikey 311-1343-1-ND
J301: FingerTouchPad; FingerTouchPad_34x35mm
R301, R302, R305: 10K; R_0603_1608Metric; digikey 13-RC0603JR-1010KLCT-ND
R303, R304: 150R; R_0603_1608Metric; digikey 311-150GRCT-ND
SW301: 3.5x2.6 Tact SW; WS-TASV SMT Tact Switch; digikey 732-435151014824CT-ND
TP301: RESET; TestPoint_Pad_D1.0mm
TP302: BOOT; TestPoint_Pad_D1.0mm
U301: ESP32-S3-WROOM-1-N16R8; ESP32-S3-WROOM-1_EXP; digikey 1965-ESP32-S3-WROOM-1-N16R8CT-ND
U302: SSD1331_DISPLAY; OLED SSD1331 SPI DISPLAY

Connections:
+3.3V: C302.1, R301.1, R302.1, R305.1, U301.2 (3V3), U302.2 (VDD); also elsewhere on the board
/ESP32_CONT/FANPWM: R304.2; also elsewhere on the board
/ESP32_CONT/IO0/BOOT: R302.2, SW301.3 (K), SW301.4 (A), TP302.1, U301.27 (IO0)
/ESP32_CONT/IO1/TOUCH1: J301.R1, U301.39 (IO1)
/ESP32_CONT/IO2/TOUCH2: J301.R2, U301.38 (IO2)
/ESP32_CONT/IO3/TOUCH3: J301.C6, U301.15 (IO3)
/ESP32_CONT/IO4/TOUCH4: J301.C1, U301.4 (IO4)
/ESP32_CONT/IO5/TOUCH5: J301.C2, U301.5 (IO5)
/ESP32_CONT/IO6/TOUCH6: J301.C3, U301.6 (IO6)
/ESP32_CONT/IO7/TOUCH7: J301.C4, U301.7 (IO7)
/ESP32_CONT/IO8/TOUCH8: J301.C5, U301.12 (IO8)
/ESP32_CONT/IO9/TOUCH9: J301.C7, U301.17 (IO9)
/ESP32_CONT/IO10/TOUCH10: J301.R7, U301.18 (IO10)
/ESP32_CONT/IO11/TOUCH11: J301.R6, U301.19 (IO11)
/ESP32_CONT/IO12/TOUCH12: J301.R5, U301.20 (IO12)
/ESP32_CONT/IO13/TOUCH13: J301.R4, U301.21 (IO13)
/ESP32_CONT/IO14/TOUCH14: J301.R3, U301.22 (IO14)
/ESP32_CONT/IO15/XTAL32KP: R305.2, U301.8 (IO15), U302.6 (D/C)
/ESP32_CONT/IO16/XTAL32KN: U301.9 (IO16), U302.5 (~RES)
/ESP32_CONT/IO17/ADC2_CH6: U301.10 (IO17), U302.4 (SDIN)
/ESP32_CONT/IO18: U301.11 (IO18); also elsewhere on the board
/ESP32_CONT/IO21: U301.23 (IO21); also elsewhere on the board
/ESP32_CONT/IO38: U301.31 (IO38); also elsewhere on the board
/ESP32_CONT/IO39: U301.32 (IO39)
/ESP32_CONT/IO40: R304.1, U301.33 (IO40)
/ESP32_CONT/IO41: U301.34 (IO41); also elsewhere on the board
/ESP32_CONT/IO42: U301.35 (IO42); also elsewhere on the board
/ESP32_CONT/IO45: U301.26 (IO45), U302.3 (SCLK)
/ESP32_CONT/IO46: U301.16 (IO46)
/ESP32_CONT/IO47: R303.1, U301.24 (IO47)
/ESP32_CONT/IO48: U301.25 (IO48); also elsewhere on the board
/ESP32_CONT/RXD0/IO44: U301.36 (RXD0)
/ESP32_CONT/SENSE_SCL: R303.2; also elsewhere on the board
/ESP32_CONT/TXD0/IO43: U301.37 (TXD0)
/ESP32_CONT/USBDM: U301.13 (IO19); also elsewhere on the board
/ESP32_CONT/USBDP: U301.14 (IO20); also elsewhere on the board
/ESP32_CONT/~RESET: C301.1, R301.2, TP301.1, U301.3 (EN)
GND: C301.2, C302.2, SW301.1, SW301.2, U301.1 (GND), U301.40 (GND), U301.41 (GND), U301.42 (GND), U301.43 (GND), U301.44 (GND), U301.45 (GND), U301.46 (GND), U301.47 (GND), U301.48 (GND), U301.49 (GND), U302.1 (VSS), U302.7 (~CS); also elsewhere on the board

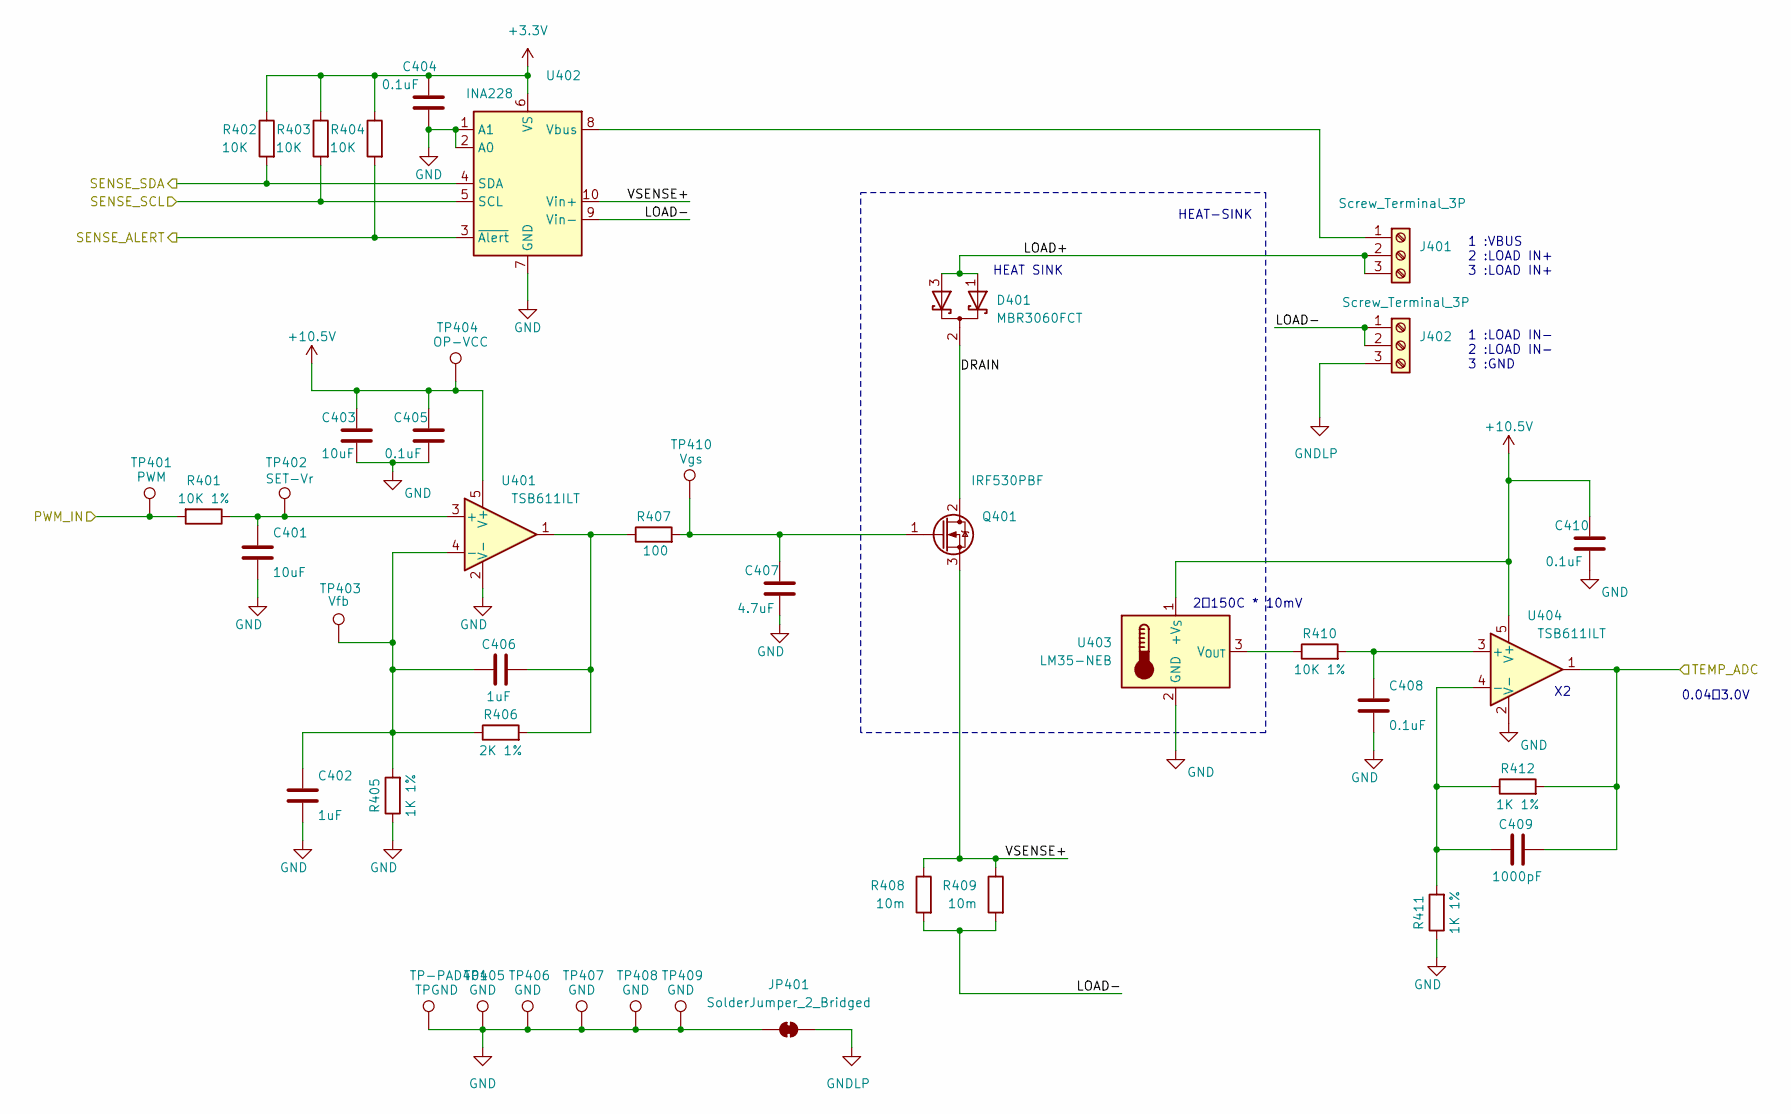
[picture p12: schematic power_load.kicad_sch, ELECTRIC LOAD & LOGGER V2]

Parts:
C401, C403: 10uF; C_0805_2012Metric; digikey 311-3494-1-ND
C402, C406: 1uF; C_0805_2012Metric; digikey 311-1365-1-ND
C404, C405, C408, C410: 0.1uF; C_0603_1608Metric; digikey 311-1343-1-ND
C407: 4.7uF; C_0805_2012Metric; digikey 311-1907-1-ND
C409: 1000pF; C_0603_1608Metric; digikey 311-4063-1-ND
D401: MBR3060FCT; TO-220-3_Horizontal_TabUp; digikey 3757-MBR3060FCT_T0_00001-ND
J401, J402: Screw_Terminal_3P; TB112-2-2-3-E-1 Terminal Block
JP401: SolderJumper_2_Bridged; SolderJumper-2_P1.3mm_Bridged_RoundedPad1.0x1.5mm
Q401: IRF530PBF; TO-220-3_Horizontal_TabUp; digikey IRF530PBF-ND
R401, R410: 10K 1%; R_0603_1608Metric; digikey 311-10.0KHRCT-ND
R402, R403, R404: 10K; R_0603_1608Metric; digikey 13-RC0603JR-1010KLCT-ND
R405, R411, R412: 1K 1%; R_0603_1608Metric; digikey 311-1.00KHRCT-ND
R406: 2K 1%; R_0603_1608Metric; digikey 311-2.00KHRCT-ND
R407: 100; R_0603_1608Metric; digikey 311-100GRCT-ND
R408, R409: 10m; R_10mOHM
TP401: PWM; TestPoint_Pad_D1.0mm
TP402: SET-Vr; TestPoint_Pad_D1.0mm
TP403: Vfb; TestPoint_Pad_D1.0mm
TP404: OP-VCC; TestPoint_Pad_D1.0mm
TP405, TP406, TP407, TP408, TP409: GND; TestPoint_Pad_D1.0mm
TP410: Vgs; TestPoint_Pad_D1.0mm
TP-PAD401: TPGND; TestPoint_Pad_3.2x1.6mm
U401, U404: TSB611ILT; SOT-23-5; digikey 497-16082-1-ND
U402: INA228; VSSOP-10_3x3mm_P0.5mm; digikey 296-INA228AIDGSRCT-ND
U403: LM35-NEB; TO-220-3_Horizontal_TabDown; digikey LM35DT/NOPB-ND

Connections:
+3.3V: C404.1, R402.1, R403.1, R404.1, U402.6 (VS); also elsewhere on the board
+10.5V: C403.1, C405.1, C410.1, TP404.1, U401.5 (V+), U403.1 (+V_{S}), U404.5 (V+); also elsewhere on the board
/ESP32_CONT/IO18: C409.2, R412.2, U404.1; also elsewhere on the board
/ESP32_CONT/IO21: R402.2, U402.4 (SDA); also elsewhere on the board
/ESP32_CONT/IO38: R401.2, TP401.1; also elsewhere on the board
/ESP32_CONT/IO48: R404.2, U402.3 (~Alert); also elsewhere on the board
/ESP32_CONT/SENSE_SCL: R403.2, U402.5 (SCL); also elsewhere on the board
/POWER_LOAD/DRAIN: D401.2 (K), Q401.2 (D)
/POWER_LOAD/LOAD+: D401.1 (A), D401.3 (A), J401.2, J401.3
/POWER_LOAD/LOAD-: J402.1, J402.2, R408.2, R409.2, U402.9 (Vin-)
/POWER_LOAD/VSENSE+: Q401.3 (S), R408.1, R409.1, U402.10 (Vin+)
GND: C401.2, C402.2, C403.2, C404.2, C405.2, C407.2, C408.2, C410.2, JP401.1 (A), R405.1, R411.1, TP405.1, TP406.1, TP407.1, TP408.1, TP409.1, TP-PAD401.1, U401.2 (V-), U402.1 (A1), U402.2 (A0), U402.7 (GND), U403.2 (GND), U404.2 (V-); also elsewhere on the board
GNDLP: J402.3, JP401.2 (B)
unnamed: C406.2, R406.2, R407.1, U401.1
unnamed: J401.1, U402.8 (Vbus)
unnamed: C407.1, Q401.1 (G), R407.2, TP410.1
unnamed: C401.1, R401.1, TP402.1, U401.3 (+)
unnamed: C402.1, C406.1, R405.2, R406.1, TP403.1, U401.4 (-)
unnamed: R410.1, U403.3 (V_{OUT})
unnamed: C408.1, R410.2, U404.3 (+)
unnamed: C409.1, R411.2, R412.1, U404.4 (-)

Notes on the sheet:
1 :VBUS 2 :LOAD IN+ 3 :LOAD IN+
0.04～3.0V
HEAT SINK
HEAT-SINK
1 :LOAD IN- 2 :LOAD IN- 3 :GND
2～150C * 10mV

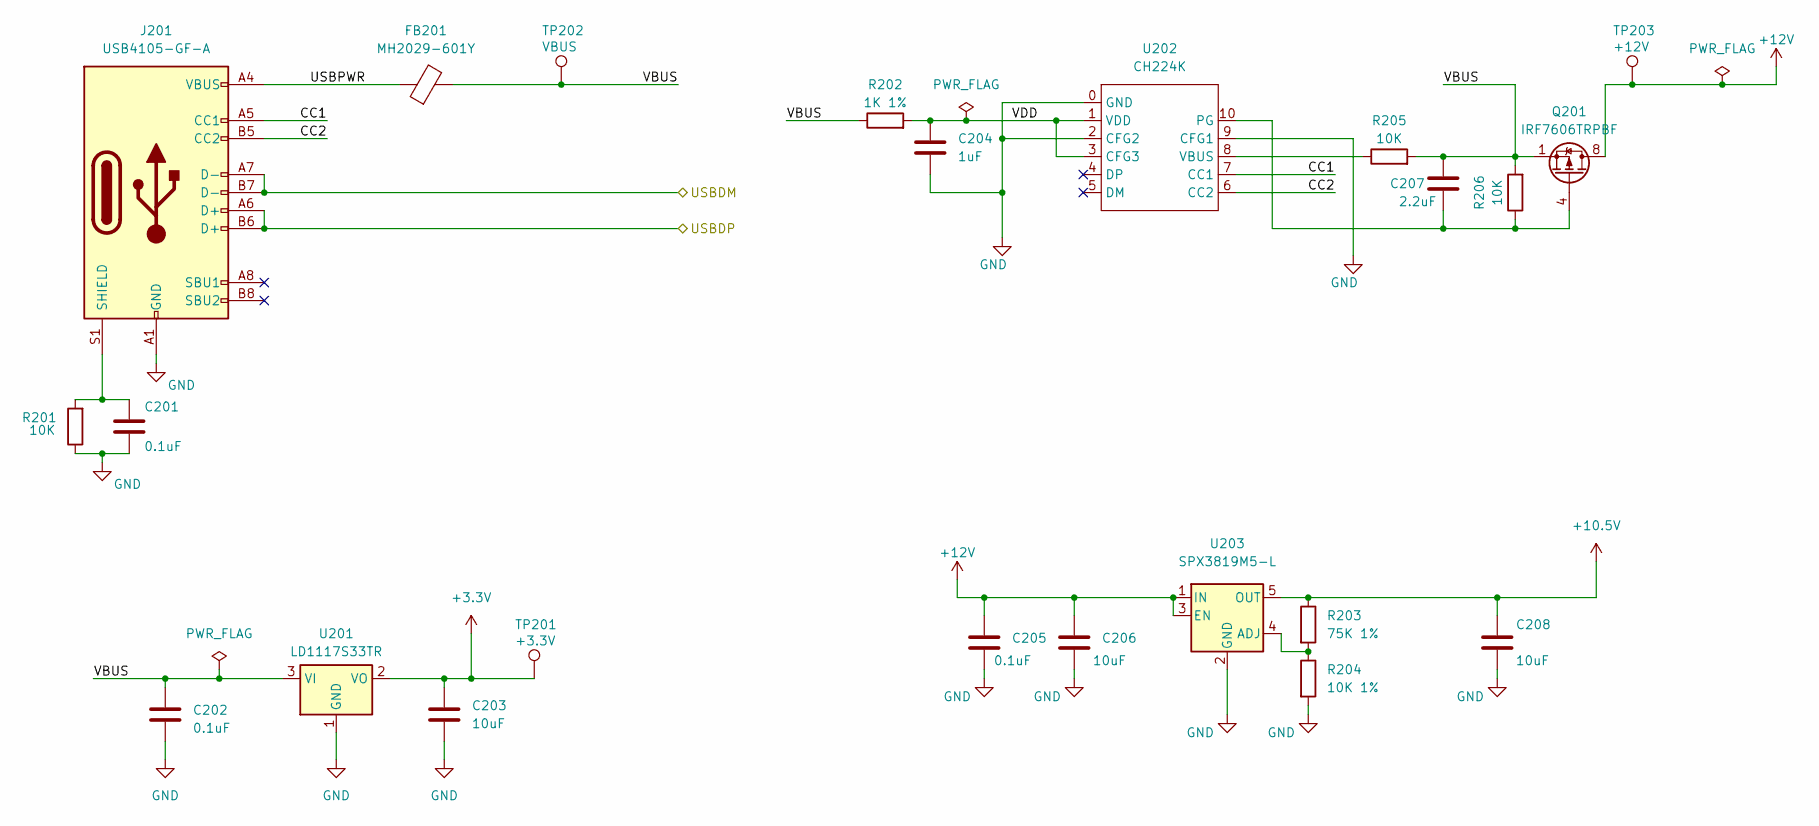
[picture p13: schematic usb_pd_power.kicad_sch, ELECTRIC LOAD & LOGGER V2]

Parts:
C201, C202, C205: 0.1uF; C_0603_1608Metric; digikey 311-1343-1-ND
C203, C206, C208: 10uF; C_0805_2012Metric; digikey 311-3494-1-ND
C204: 1uF; C_0805_2012Metric; digikey 311-1365-1-ND
C207: 2.2uF; C_0805_2012Metric; digikey 311-1463-1-ND
FB201: MH2029-601Y; L_0805_2012Metric; digikey MH2029-601YCT-ND
J201: USB4105-GF-A; USB_C_5077CR-16-SMC2-BK-TR; digikey 2073-USB4105-GF-ACT-ND
Q201: IRF7606TRPBF; MSOP-8_3x3mm_P0.65mm; digikey IRF7606TRPBFCT-ND
R201, R205, R206: 10K; R_0603_1608Metric; digikey 13-RC0603JR-1010KLCT-ND
R202: 1K 1%; R_0603_1608Metric; digikey 311-1.00KHRCT-ND
R203: 75K 1%; R_0603_1608Metric; digikey YAG3629CT-ND
R204: 10K 1%; R_0603_1608Metric; digikey 311-10.0KHRCT-ND
TP201: +3.3V; TestPoint_Pad_D1.0mm
TP202: VBUS; TestPoint_Pad_D1.0mm
TP203: +12V; TestPoint_Pad_D1.0mm
U201: LD1117S33TR; SOT-223-3_TabPin2; digikey 497-1242-1-ND
U202: CH224K; ESSOP-10_3.9x4.9mm_P1.00mm
U203: SPX3819M5-L; SOT-23-5; digikey 1016-1871-1-ND

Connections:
+3.3V: C203.1, TP201.1, U201.2 (VO); also elsewhere on the board
+10.5V: C208.1, R203.1, U203.5 (OUT); also elsewhere on the board
+12V: C205.1, C206.1, Q201.5 (D), Q201.6 (D), Q201.7 (D), Q201.8 (D), TP203.1, U203.1 (IN), U203.3 (EN); also elsewhere on the board
/ESP32_CONT/USBDM: J201.A7 (D-), J201.B7 (D-); also elsewhere on the board
/ESP32_CONT/USBDP: J201.A6 (D+), J201.B6 (D+); also elsewhere on the board
/USBPDPower/CC1: J201.A5 (CC1), U202.7 (CC1)
/USBPDPower/CC2: J201.B5 (CC2), U202.6 (CC2)
/USBPDPower/USBPWR: FB201.1, J201.A4 (VBUS), J201.A9 (VBUS), J201.B4 (VBUS), J201.B9 (VBUS)
/USBPDPower/VBUS: C202.1, C207.1, FB201.2, Q201.1 (S), Q201.2 (S), Q201.3 (S), R202.1, R205.2, R206.2, TP202.1, U201.3 (VI)
/USBPDPower/VDD: C204.1, R202.2, U202.1 (VDD), U202.3 (CFG3)
GND: C201.2, C202.2, C203.2, C204.2, C205.2, C206.2, C208.2, J201.A1 (GND), J201.A12 (GND), J201.B1 (GND), J201.B12 (GND), R201.1, R204.2, U201.1 (GND), U202.0 (GND), U202.2 (CFG2), U202.9 (CFG1), U203.2 (GND); also elsewhere on the board
unnamed: C201.1, J201.S1 (SHIELD), R201.2
unnamed: C207.2, Q201.4 (G), R206.1, U202.10 (PG)
unnamed: R205.1, U202.8 (VBUS)
unnamed: R203.2, R204.1, U203.4 (ADJ)

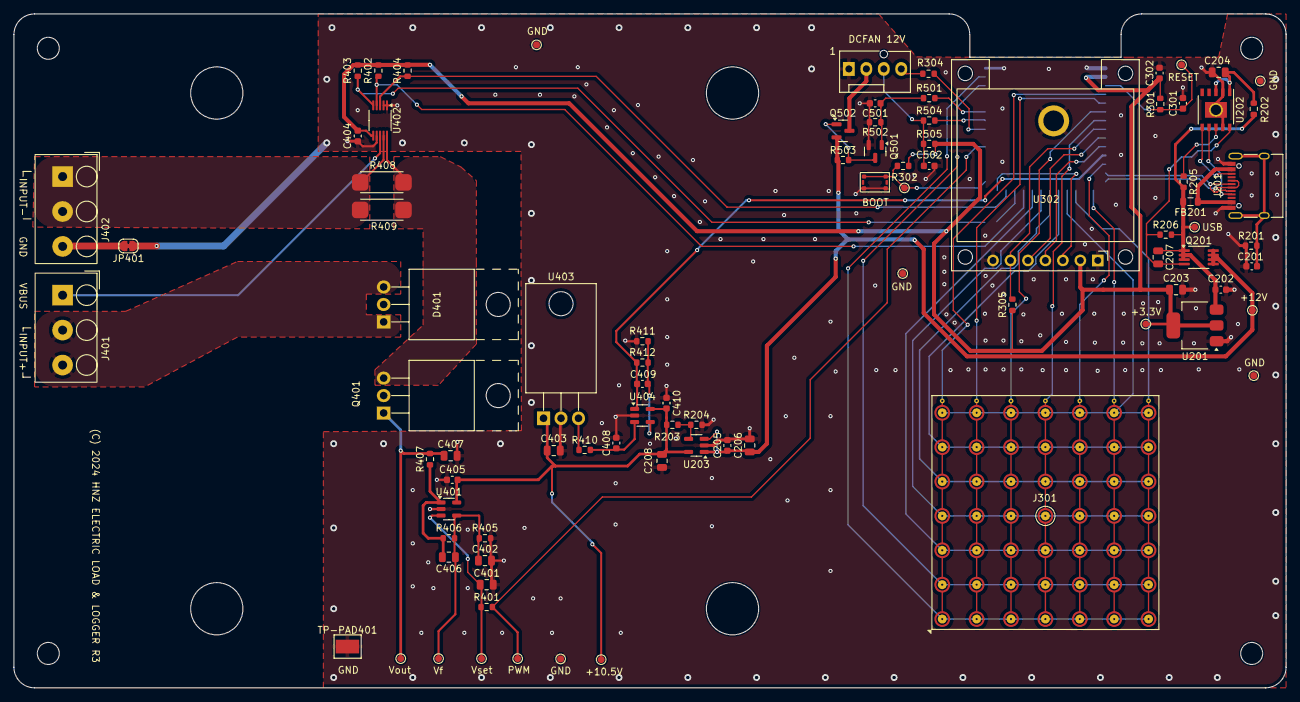
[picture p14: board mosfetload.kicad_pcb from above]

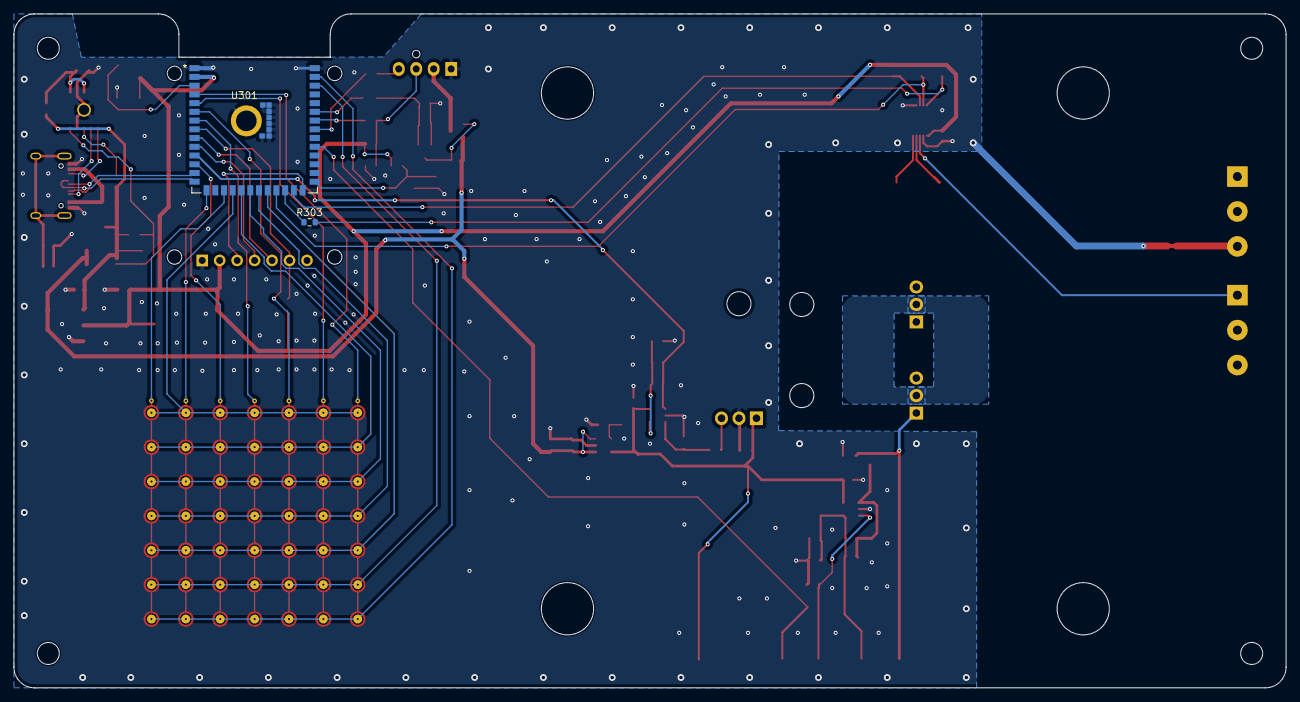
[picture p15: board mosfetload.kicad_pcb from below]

Board: 2 copper layers, 185.0 x 98.0 mm, 88 parts (2 on the bottom side), 62 nets.

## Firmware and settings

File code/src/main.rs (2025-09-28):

// This is electric-load main program for ESP32-S3-WROOM-1-N16R8.
// SPDX-License-Identifier: MIT
// Copyright (c) 2024-2025 Hiroshi Nakajima

use std::{thread, time::Duration};
use esp_idf_hal::{gpio::*, prelude::*, spi, i2c};
use esp_idf_hal::delay::BLOCK;
use esp_idf_hal::peripherals::Peripherals;
use embedded_hal::spi::MODE_0;
use log::*;
use std::time::SystemTime;
use esp_idf_hal::adc::oneshot::config::AdcChannelConfig as AdcConfig;
use esp_idf_hal::adc::oneshot::config::Calibration;
use esp_idf_hal::adc::oneshot::*;
use esp_idf_hal::adc::attenuation::DB_11;
use esp_idf_hal::ledc::config::TimerConfig;
use esp_idf_hal::ledc::LedcTimerDriver;
use esp_idf_hal::ledc::LedcDriver;
use esp_idf_svc::sntp::{EspSntp, SyncStatus, SntpConf, OperatingMode, SyncMode};
use esp_idf_svc::wifi::EspWifi;
use esp_idf_svc::nvs::*;
use chrono::{DateTime, Utc};

mod displayctl;
mod currentlogs;
mod wifi;
mod transfer;
mod touchpad;
mod pidcont;
mod pulscount;

use displayctl::{DisplayPanel, LoggingStatus, WifiStatus};
use currentlogs::{CurrentRecord, CurrentLog};
use transfer::{Transfer, ServerInfo};
use touchpad::{TouchPad, Key};
use pidcont::PIDController;
use pulscount::PulsCountDriver;

#[toml_cfg::toml_config]
pub struct Config {
    #[default("")]
    wifi_ssid: &'static str,                // Your WiFi SSID
    #[default("")]
    wifi_psk: &'static str,                 // Your WiFi Password
    #[default("")]
    influxdb_server: &'static str,          // InfluxDB Server Address
    #[default("0.00001")]
    pid_kp: &'static str,                   // PID Controller Kp
    #[default("0.05")]
    pid_ki: &'static str,                   // PID Controller Ki
    #[default("0.000001")]
    pid_kd: &'static str,                   // PID Controller Kd
    #[default("4500")]
    pwm_offset: &'static str,               // PWM Offset
    #[default("11.0")]
    max_current_limit: &'static str,        // Maximum Current Limit
    #[default("110.0")]
    max_power_limit: &'static str,          // Maximum Power Limit
    #[default("1.1")]
    max_current_limit_ratio: &'static str,  // Maximum Current Limit Ratio to Set Current
    #[default("0.1")]
    under_voltage_limit: &'static str,      // Under Voltage Limit
    #[default("")]
    influxdb_api_key: &'static str,         // InfluxDB API Key
    #[default("")]
    influxdb_api: &'static str,             // InfluxDB API Path
    #[default("")]
    influxdb_measurement: &'static str,     // InfluxDB Measurement Name
    #[default("")]
    influxdb_tag: &'static str,             // InfluxDB Tag Name
}

// NVS key for storing the last load current setting
const NVS_KEY_LOAD_CURRENT: &str = "load_current";

// Load the last saved load current from NVS
fn load_current_from_nvs(nvs: &mut EspNvs<NvsDefault>) -> f32 {
    match nvs.get_i32(NVS_KEY_LOAD_CURRENT) {
        Ok(Some(current_i32)) => {
            let current = current_i32 as f32 / 1000.0;
            info!("Loaded last load current from NVS: {:.3}A", current);
            current
        },
        Ok(None) => {
            info!("No saved load current found in NVS, using default 0.0A");
            0.0
        },
        Err(e) => {
            info!("Error reading load current from NVS: {:?}, using default 0.0A", e);
            0.0
        }
    }
}

// Save the current load setting to NVS
fn save_current_to_nvs(nvs: &mut EspNvs<NvsDefault>, current: f32) -> anyhow::Result<()> {
    let current_i32 = (current * 1000.0) as i32;
    match nvs.set_i32(NVS_KEY_LOAD_CURRENT, current_i32) {
        Ok(()) => {
            info!("Saved load current to NVS: {:.3}A", current);
            Ok(())
        },
        Err(e) => {
            info!("Error saving load current to NVS: {:?}", e);
            Err(e.into())
        }
    }
}

fn main() -> anyhow::Result<()> {
    esp_idf_sys::link_patches();
    esp_idf_svc::log::EspLogger::initialize_default();

    // Initialize nvs
    unsafe {
        esp_idf_sys::nvs_flash_init();
    }

    // Initialize NVS partition for storing settings
    let nvs_default_partition = EspDefaultNvsPartition::take()?;
    let mut nvs = EspNvs::new(nvs_default_partition, "storage", true)?;

    // Peripherals Initialize
    let peripherals = Peripherals::take().unwrap();
    
    // Load Config
    let max_current_limit = CONFIG.max_current_limit.parse::<f32>().unwrap();
    let max_power_limit = CONFIG.max_power_limit.parse::<f32>().unwrap();
    let max_current_limit_ratio = CONFIG.max_current_limit_ratio.parse::<f32>().unwrap();
    let under_voltage_limit = CONFIG.under_voltage_limit.parse::<f32>().unwrap();
    info!("[Limit] Current: {}A  Power: {}W  Current Ratio: {}  Under Voltage: {}V", max_current_limit, max_power_limit, max_current_limit_ratio, under_voltage_limit);
    let server_info = ServerInfo::new(CONFIG.influxdb_server.to_string(), 
        CONFIG.influxdb_api_key.to_string(),
        CONFIG.influxdb_api.to_string(),
        CONFIG.influxdb_measurement.to_string(),
        CONFIG.influxdb_tag.to_string());

    // Display SPI
    let spi = peripherals.spi2;
    let sclk = peripherals.pins.gpio45;
    let sdo  = peripherals.pins.gpio17;
    let sdi_not_used : Option<Gpio2> = None;
    let cs_not_used : Option<Gpio2> = None;
    let dc = PinDriver::output(peripherals.pins.gpio15)?;
    let rst = PinDriver::output(peripherals.pins.gpio16)?;
    let spi_config = spi::SpiConfig::new().baudrate(1.MHz().into()).data_mode(MODE_0);
    let spi_driver_config = spi::config::DriverConfig::new();

    let spi_driver = spi::SpiDriver::new(
        spi,
        sclk,
        sdo,
        sdi_not_used,
        &spi_driver_config
    ).unwrap();
    
    let spi_device = spi::SpiDeviceDriver::new(spi_driver, cs_not_used, &spi_config)?;
    let mut dp = DisplayPanel::new();
    dp.start(spi_device, dc, rst);

    // Current/Voltage
    let i2c = peripherals.i2c0;
    let scl = peripherals.pins.gpio47;
    let sda = peripherals.pins.gpio21;
    let config = i2c::I2cConfig::new().baudrate(400.kHz().into());
    let mut i2cdrv = i2c::I2cDriver::new(i2c, sda, scl, &config)?;

    // INA228
    // Config
    let mut config_read_buf = [0u8; 2];
    let mut config_write_buf = [0u8; 3];
    // read config
    i2cdrv.write(0x40, &[0x01u8; 1], BLOCK)?;
    i2cdrv.read(0x40, &mut config_read_buf, BLOCK)?;
    config_write_buf[0] = 0x01;
    config_write_buf[1] = config_read_buf[0];
    config_write_buf[2] = (config_read_buf[1] & 0xF8) | 0x02; // 0x02: 16avg, 0x03: 64avg
    i2cdrv.write(0x40, &config_write_buf, BLOCK)?;
    // read back
    i2cdrv.write(0x40, &[0x01u8; 1], BLOCK)?;
    i2cdrv.read(0x40, &mut config_read_buf, BLOCK)?;
    info!("INA228 Config: {:02X}{:02X}", config_read_buf[0], config_read_buf[1]);
    // Calibration
    // SHUNT_CAL
    let current_lsb = 16.384 / 524_288.0;
    let shunt_cal_val = 13107.2 * current_lsb * 1000_000.0 * 0.005;
    let shunt_cal = shunt_cal_val as u32;
    info!("current_lsb={:?} shunt_cal_val={:?} shunt_cal={:?}", current_lsb, shunt_cal_val, shunt_cal);
    let mut shunt_cal_buf = [0u8; 3];
    shunt_cal_buf[0] = 0x02;
    shunt_cal_buf[1] = (shunt_cal >> 8) as u8;
    shunt_cal_buf[2] = (shunt_cal & 0xFF) as u8;
    i2cdrv.write(0x40, &shunt_cal_buf, BLOCK)?;
    // read back
    let mut shunt_cal_read_buf = [0u8; 2];
    i2cdrv.write(0x40, &[0x02u8; 1], BLOCK)?;
    i2cdrv.read(0x40, &mut shunt_cal_read_buf, BLOCK)?;
    if shunt_cal_read_buf[0] != shunt_cal_buf[1] || shunt_cal_read_buf[1] != shunt_cal_buf[2] {
        info!("shunt_cal_write_buf={:?}", shunt_cal_buf);
        info!("shunt_cal_read_buf={:?}", shunt_cal_read_buf);
        info!("Shunt Calibration Error");
    }

    // PWM
    let timer_config_out_current = TimerConfig::default().frequency(1.kHz().into())
        .resolution(esp_idf_hal::ledc::config::Resolution::Bits14);
    let timer_driver_0 = LedcTimerDriver::new(peripherals.ledc.timer0, &timer_config_out_current).unwrap();
    let mut pwm_driver = LedcDriver::new(peripherals.ledc.channel0, &timer_driver_0, peripherals.pins.gpio38).unwrap();
    pwm_driver.set_duty(0).expect("Set duty failure");
    let max_duty = pwm_driver.get_max_duty();
    info!("Max duty: {}", max_duty);
    // FAN PWM
    let timer_config_fan = TimerConfig::default().frequency(1.kHz().into())
        .resolution(esp_idf_hal::ledc::config::Resolution::Bits8);
    let timer_driver_1 = LedcTimerDriver::new(peripherals.ledc.timer1, &timer_config_fan).unwrap();
    let mut fan_pwm_driver = LedcDriver::new(peripherals.ledc.channel1, &timer_driver_1, peripherals.pins.gpio40).unwrap();
    fan_pwm_driver.set_duty(0).expect("Set duty failure");
    let max_fan_duty = fan_pwm_driver.get_max_duty();
    info!("Max duty: {}", max_fan_duty);

    // FAN POWER
    let mut fan_on = PinDriver::output(peripherals.pins.gpio42).unwrap();
    fan_on.set_low().unwrap();
    // FAN DETECT
    let fan_det = Box::new(PinDriver::input(peripherals.pins.gpio41).unwrap());
    let mut pulscnt = PulsCountDriver::new();
    pulscnt.start(fan_det);
    
    // Temperature Logs
    let mut clogs = CurrentRecord::new();

    // WiFi
    let mut wifi_enable : bool;
    let mut wifi_dev = wifi::wifi_connect(peripherals.modem, CONFIG.wifi_ssid, CONFIG.wifi_psk);
        
    // NTP Server
    let sntp_conf = SntpConf {
        servers: ["time.aws.com",
                    "time.google.com",
                    "time.cloudflare.com",
                    "ntp.nict.jp"],
        operating_mode: OperatingMode::Poll,
        sync_mode: SyncMode::Immediate,
    };
    let ntp = EspSntp::new(&sntp_conf).unwrap();

    // NTP Sync
    // let now = SystemTime::now();
    // if now.duration_since(UNIX_EPOCH).unwrap().as_millis() < 1700000000 {
    info!("NTP Sync Start..");

    // wait for sync
    let mut sync_count = 0;
    while ntp.get_sync_status() != SyncStatus::Completed {
        sync_count += 1;
        if sync_count > 1000 {
            info!("NTP Sync Timeout");
            break;
        }
        thread::sleep(Duration::from_millis(10));
    }
    let now = SystemTime::now();
    let dt_now : DateTime<Utc> = now.into();
    let formatted = format!("{}", dt_now.format("%Y-%m-%d %H:%M:%S"));
    info!("NTP Sync Completed: {}", formatted);
        
    let mut txd =  Transfer::new(server_info);
    txd.start()?;

    // TouchPad
    let mut touchpad = TouchPad::new();
    touchpad.start();

    // ADC2-CH7 GPIO18 for Temperature
    let mut adc_temp = AdcDriver::new(peripherals.adc2)?;
    let mut adc_temp_config = AdcConfig {
        attenuation: DB_11,
        calibration: Calibration::Curve,
        .. AdcConfig::default()
    };
    let mut temp_pin = AdcChannelDriver::new(&mut adc_temp, peripherals.pins.gpio18, &mut adc_temp_config)?;


    // PID Controller
    let pid_kp = CONFIG.pid_kp.parse::<f32>().unwrap();
    let pid_ki = CONFIG.pid_ki.parse::<f32>().unwrap();
    let pid_kd = CONFIG.pid_kd.parse::<f32>().unwrap();
    let pwm_offset = CONFIG.pwm_offset.parse::<u32>().unwrap();
    info!("PID Controller: KP={} KI={} KD={}", pid_kp, pid_ki, pid_kd);
    let mut pid = PIDController::new(pid_kp, pid_ki, pid_kd, 0.0);

    // Start Display
    dp.enable_display(true);

    // loop
    let mut measurement_count : u32 = 0;
    let mut logging_start = false;
    let mut load_start = false;
    let mut set_load_current = load_current_from_nvs(&mut nvs);
    dp.set_load_current(set_load_current);
    let mut pwm_duty;
    loop {
        thread::sleep(Duration::from_millis(10));

        let mut start_stop_btn = false;
        measurement_count += 1;
        if measurement_count % 5 == 0 {
            let touch_event : Vec<Key> = touchpad.tocuhpad_key_event();
            for touch in &touch_event {
                match touch {
                    Key::None => {},
                    // Key::Left => { interval_select_btn = true; },
                    Key::Center => { start_stop_btn = true; },
                    Key::Clockwise => {
                        set_load_current += 0.01;
                        dp.set_load_current(set_load_current);
                    },
                    Key::CounterClockwise => {
                        if set_load_current > 0.0 {
                            set_load_current -= 0.01;
                        }
                        dp.set_load_current(set_load_current);
                    },
                    _ => {},
                }
            }
        }
        if start_stop_btn == true {
            if load_start == true {
                // to Stop
                logging_start = false;
                load_start = false;
                // clogs.dump();
                // clogs.clear();
            }
            else {
                // to Start
                logging_start = true;
                load_start = true;
                measurement_count = 0;
                info!("Logging and Sending Start..");
                // Save current load setting to NVS when starting
                if let Err(e) = save_current_to_nvs(&mut nvs, set_load_current) {
                    info!("Failed to save load current to NVS: {:?}", e);
                }
                pid.reset();
                clogs.clear();
                dp.enable_display(true);
            }
        }

        let rssi = wifi::get_rssi();
        if rssi == 0 {
            wifi_enable = false;
            if measurement_count % 1000 == 0 {
                wifi_reconnect(&mut wifi_dev.as_mut().unwrap());
            }
        }
        else {
            wifi_enable = true;
        }

        if wifi_enable == false {
            dp.set_wifi_status(WifiStatus::Disconnected);
        }
        else {
            dp.set_wifi_status(WifiStatus::Connected);
        }

        if load_start == true {
            fan_on.set_high().unwrap();
            pid.set_setpoint(set_load_current);
            dp.set_current_status(LoggingStatus::Start);
        }
        else {
            dp.set_current_status(LoggingStatus::Stop);
        }

        // Read Current/Voltage
        let mut vbus_buf  = [0u8; 3];
        let mut data = CurrentLog::default();
        // Timestamp
        let now = SystemTime::now();
        // set clock in ns
        data.clock = now.duration_since(SystemTime::UNIX_EPOCH).unwrap().as_nanos();

        i2cdrv.write(0x40, &[0x05u8; 1], BLOCK)?;
        match i2cdrv.read(0x40, &mut vbus_buf, BLOCK){
            Ok(_v) => {
                let vbus = ((((vbus_buf[0] as u32) << 16 | (vbus_buf[1] as u32) << 8 | (vbus_buf[2] as u32)) >> 4) as f32 * 195.3125) / 1000_000.0;
                data.voltage = vbus; // V
                // info!("vbus={:?} {:?}V", vbus_buf, data.voltage);
            },
            Err(e) => {
                info!("{:?}", e);
                dp.set_message(format!("{:?}", e));
            }
        }
        let mut curt_buf  = [0u8; 3];
        i2cdrv.write(0x40, &[0x07u8; 1], BLOCK)?;
        match i2cdrv.read(0x40, &mut curt_buf, BLOCK) {
            Ok(_v) => {
                let current_reg : f32;
                if curt_buf[0] & 0x80 == 0x80 {
                    current_reg = (0x100000 - (((curt_buf[0] as u32) << 16 | (curt_buf[1] as u32) << 8 | (curt_buf[2] as u32)) >> 4)) as f32 * -1.0;
                }
                else {
                    current_reg = (((curt_buf[0] as u32) << 16 | (curt_buf[1] as u32) << 8 | (curt_buf[2] as u32)) >> 4) as f32;
                }
                let current = current_lsb * current_reg;
                data.current = current;   // A
                // info!("curt={:?} {:?}A", curt_buf, data.current);
            },
            Err(e) => {
                info!("{:?}", e);
                dp.set_message(format!("{:?}", e));
            }
        }
        // Power
        let mut power_buf = [0u8; 3];
        i2cdrv.write(0x40, &[0x08u8; 1], BLOCK)?;
        match i2cdrv.read(0x40, &mut power_buf, BLOCK) {
            Ok(_v) => {
                // info!("power={:?}", power_buf);
                let power_reg = ((power_buf[0] as u32) << 16 | (power_buf[1] as u32) << 8 | (power_buf[2] as u32)) as f32;
                let power = 3.2 * current_lsb * power_reg;        
                data.power = power;   // W
            },
            Err(e) => {
                info!("{:?}", e);
                dp.set_message(format!("{:?}", e));
            }
        }
        // Current and Power Limit
        if data.current > max_current_limit {
            info!("Current Limit Over: {:.3}A", data.current);
            dp.set_message(format!("CLO {:.3}A", data.current));
            load_start = false;
        }
        if data.power > max_power_limit {
            info!("Power Limit Over: {:.1}W", data.power);
            dp.set_message(format!("PLO {:.1}W", data.power));
            load_start = false;
        }

        // Temperature
        let temp = temp_pin.read().unwrap() as f32 * 0.05;
        data.temp = temp;
        // info!("Temperature: {:.2}°C", temp);
        dp.set_temperature(temp);
        let fan_duty = fan_pwm_control(temp, max_fan_duty);
        if load_start == false && fan_duty == 0 {
            fan_on.set_low().unwrap();
        }
        fan_pwm_driver.set_duty(fan_duty).expect("Set duty failure");
        // FAN RPM
        let rpm = pulscnt.get_rpm();
        data.rpm = rpm;
        dp.set_voltage(data.voltage, data.current, data.power);
        if data.voltage < under_voltage_limit || (data.current > set_load_current * max_current_limit_ratio) {
            // no voltage, over current
            pid.reset();
            pwm_duty = 0;
        }
        else {
            // PID Control  
            let pid_out = pid.update(data.current);
            pwm_duty = (pid_out * (max_duty as f32)) as u32 + pwm_offset;
        }    
        // info!("Current {:.3}A PID OUT {} -> Duty: {} ", average_current, pid_out, pwm_duty);
        // PID Control
        if pwm_duty > max_duty {
            pwm_duty = max_duty;
        }
        if load_start == false {
            pwm_duty = 0;
        }
        pwm_driver.set_duty(pwm_duty).expect("Set duty failure");
        dp.set_pwm_duty(pwm_duty);
        data.pwm = pwm_duty;
        if logging_start {
            clogs.record(data);
        }
        let current_record = clogs.get_size();
        if current_record >= 4095 {
            logging_start = false;  // Auto stop logging if buffer is full.
        }
        dp.set_buffer_watermark((current_record as u32) * 100 / 4095);

        if wifi_enable == true && current_record > 0 {
            let logs = clogs.get_all_data();
            let txcount = txd.set_transfer_data(logs);
            if txcount > 0 {
                clogs.remove_data(txcount);
            }
        }
    }
}

fn fan_pwm_control(current_temp: f32, max_duty: u32) -> u32 {
    let duty;
    if current_temp > 50.0 {
        duty = max_duty;
    }
    else if current_temp > 40.0 {
        duty = max_duty * ((current_temp - 40.0) as u32 + 1) / 10;
    }
    else {
        duty = 0;
    }
    duty
}

fn wifi_reconnect(wifi_dev: &mut EspWifi) -> bool{
    unsafe {
        esp_idf_sys::esp_wifi_start();
    }
    match wifi_dev.connect() {
        Ok(_) => { info!("Wifi connecting requested."); true},
        Err(ref e) => { info!("{:?}", e); false }
    }
}

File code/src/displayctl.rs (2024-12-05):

// Display control module for SSD1331 OLED display.
// SPDX-License-Identifier: MIT
// Copyright (c) 2024 Hiroshi Nakajima

#![allow(dead_code)]

use log::*;
use std::{thread, time::Duration, sync::Arc, sync::Mutex};
use esp_idf_hal::{gpio::*, spi, delay::FreeRtos};
use ssd1331::{DisplayRotation, Ssd1331};
use embedded_graphics::{
    mono_font::{ascii::FONT_10X20, ascii::FONT_5X8, ascii::FONT_6X12, MonoTextStyle},
    image::Image,
    pixelcolor::{Rgb565},
    text::{Text},
    geometry::Point,
    primitives::{
        Circle, Line, Triangle, PrimitiveStyle,
    },
    prelude::*,
};
use tinybmp::Bmp;

pub enum LoggingStatus {
    Start,
    Stop,
}

pub enum WifiStatus {
    Connected,
    Disconnected,
}

type SPI<'d> = esp_idf_hal::spi::SpiDeviceDriver<'static, spi::SpiDriver<'static>>;
type DC<'d> = esp_idf_hal::gpio::PinDriver<'static, Gpio15, esp_idf_hal::gpio::Output>;
type RST<'d> = esp_idf_hal::gpio::PinDriver<'static, Gpio16, esp_idf_hal::gpio::Output>;

struct DisplayText {
    display_enable: bool,
    voltage: f32,
    current: f32,
    power: f32,
    interval: u32,
    message: String,
    message_enable: bool,
    battery: f32,
    status: LoggingStatus,
    wifi: WifiStatus,
    buffer_water_mark: u32,
    load_current: f32,
    temperature: f32,
    pwm_duty: u32,
}

pub struct DisplayPanel {
    txt: Arc<Mutex<DisplayText>>
}

impl DisplayPanel {

    pub fn new() -> DisplayPanel {
        DisplayPanel { txt: Arc::new(Mutex::new(
            DisplayText {display_enable: false,
                         voltage: 0.0,
                         message: "".to_string(),
                         message_enable: false,
                         current: 0.0,
                         power: 0.0,
                         interval: 0,
                         battery: 0.0,
                         status: LoggingStatus::Stop,
                         wifi: WifiStatus::Disconnected,
                         buffer_water_mark: 0,
                         load_current: 0.0,
                         temperature: 0.0,
                         pwm_duty: 0,
                     })) }
    }

    pub fn start(&mut self,
        spi : SPI, dc: DC, mut rst : RST)
    {
        let txt = self.txt.clone();
        let _th = thread::spawn(move || {
            info!("Start Display Thread.");
            let mut delay = FreeRtos;
            let mut display = Ssd1331::new(spi, dc, DisplayRotation::Rotate0);
            let _ = display.reset(&mut rst, &mut delay);
            let _ = display.init();
            display.clear();
            let _style = MonoTextStyle::new(&FONT_10X20, Rgb565::WHITE);
            let middle_style_white = MonoTextStyle::new(&FONT_6X12, Rgb565::WHITE);
            let middle_style_red = MonoTextStyle::new(&FONT_6X12, Rgb565::RED);
            let middle_style_yellow = MonoTextStyle::new(&FONT_6X12, Rgb565::YELLOW);
            let middle_style_blue = MonoTextStyle::new(&FONT_6X12, Rgb565::BLUE);
            let _small_style_white = MonoTextStyle::new(&FONT_5X8, Rgb565::WHITE);
            let wifibmp = Bmp::from_slice(include_bytes!("./img/wifirev.bmp")).unwrap();
            let wifi_img: Image<Bmp<Rgb565>> = Image::new(&wifibmp, Point::new(86, 47));
            let fill = PrimitiveStyle::with_fill(Rgb565::YELLOW);
            // Logo BMP
            let logobmp = Bmp::from_slice(include_bytes!("./img/logo.bmp")).unwrap();
            let logo_img: Image<Bmp<Rgb565>> = Image::new(&logobmp, Point::new(0,0));

            // Number BMP
            let n0 = Bmp::from_slice(include_bytes!("./img/n0.bmp")).unwrap();
            let n0_img: Image<Bmp<Rgb565>> = Image::new(&n0, Point::zero());
            let n1 = Bmp::from_slice(include_bytes!("./img/n1.bmp")).unwrap();
            let n1_img: Image<Bmp<Rgb565>> = Image::new(&n1, Point::zero());
            let n2 = Bmp::from_slice(include_bytes!("./img/n2.bmp")).unwrap();
            let n2_img: Image<Bmp<Rgb565>> = Image::new(&n2, Point::zero());
            let n3 = Bmp::from_slice(include_bytes!("./img/n3.bmp")).unwrap();
            let n3_img: Image<Bmp<Rgb565>> = Image::new(&n3, Point::zero());
            let n4 = Bmp::from_slice(include_bytes!("./img/n4.bmp")).unwrap();
            let n4_img: Image<Bmp<Rgb565>> = Image::new(&n4, Point::zero());
            let n5 = Bmp::from_slice(include_bytes!("./img/n5.bmp")).unwrap();
            let n5_img: Image<Bmp<Rgb565>> = Image::new(&n5, Point::zero());
            let n6 = Bmp::from_slice(include_bytes!("./img/n6.bmp")).unwrap();
            let n6_img: Image<Bmp<Rgb565>> = Image::new(&n6, Point::zero());
            let n7 = Bmp::from_slice(include_bytes!("./img/n7.bmp")).unwrap();
            let n7_img: Image<Bmp<Rgb565>> = Image::new(&n7, Point::zero());
            let n8 = Bmp::from_slice(include_bytes!("./img/n8.bmp")).unwrap();
            let n8_img: Image<Bmp<Rgb565>> = Image::new(&n8, Point::zero());
            let n9 = Bmp::from_slice(include_bytes!("./img/n9.bmp")).unwrap();
            let n9_img: Image<Bmp<Rgb565>> = Image::new(&n9, Point::zero());
            // let vv = Bmp::from_slice(include_bytes!("./img/v.bmp")).unwrap();
            // let vv_img: Image<Bmp<Rgb565>> = Image::new(&vv, Point::new(68, 0));
            let amp = Bmp::from_slice(include_bytes!("./img/A.bmp")).unwrap();
            let amp_img: Image<Bmp<Rgb565>> = Image::new(&amp, Point::new(88, 0));
            let dot = Bmp::from_slice(include_bytes!("./img/dot.bmp")).unwrap();
            let dot_img: Image<Bmp<Rgb565>> = Image::new(&dot, Point::zero());
            let minus = Bmp::from_slice(include_bytes!("./img/minus.bmp")).unwrap();
            let minus_img: Image<Bmp<Rgb565>> = Image::new(&minus, Point::zero());
            let mut digit_img = n0_img.translate(Point::new(0,0));
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

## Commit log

2024-11-24 The digit of FAN rpm is 0
2024-11-25 Add pcb documents
    [bom.csv, esp32_cont.kicad_sch, fanctl.kicad_sch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]
2024-11-25 Add how to connect power source to the terminal
2024-12-03 Update PCB data
    [bom.csv]
2024-12-04 Add PCB order info
2024-12-05 Fixed display consumed power mW
    [displayctl.rs]
2024-12-29 Changed OpAMP part no.
    [bom.csv, fanctl.kicad_sch, power_load.kicad_sch]
2024-12-29 Update BOM list
    [bom.csv]

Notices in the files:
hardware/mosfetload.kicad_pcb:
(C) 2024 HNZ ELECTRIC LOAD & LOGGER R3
